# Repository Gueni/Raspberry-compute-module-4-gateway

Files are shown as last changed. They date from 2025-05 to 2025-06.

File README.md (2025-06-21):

# Compute Module 4 Gateway

Compact industrial-grade gatewaysolution based on Raspberry Pi Compute Module 4 (CM4) with extensive connectivity options including USB, Ethernet, cellular, and more.

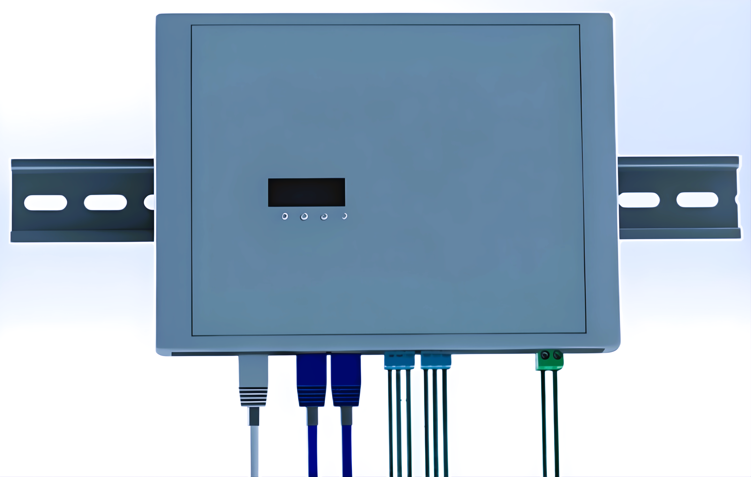
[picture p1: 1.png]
Gateway Overview

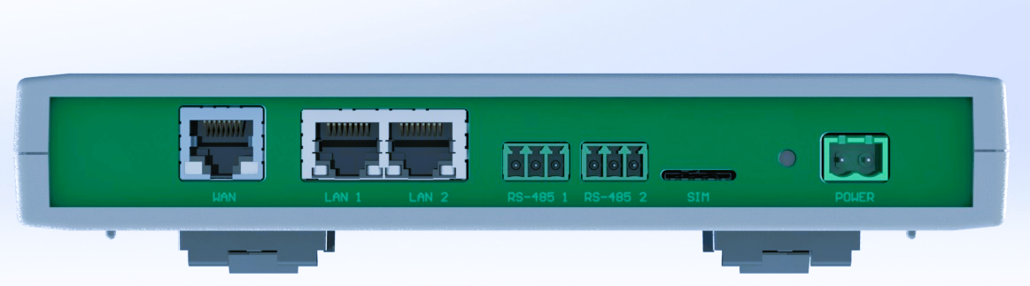
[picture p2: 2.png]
Gateway bottom

## Features

- **Raspberry Pi CM4** at its core
- **Dual Power Supply** with LMR33640 switching regulators
- **USB Hub** with USB2514B controller (4 downstream ports)
- **Cellular Connectivity** via LARA-R6 4G/LTE module
- **Dual Ethernet** with LAN9500A controllers
- **SD Card Interface** with MAX4996 selection.
- **Real-Time Clock** (MCP7940NT)
- **Supervisory Circuitry** with PIC16F18857
- **OLED Display** interface (128x32)
- **Multiple GPIO** breakout options

## Hardware Specifications
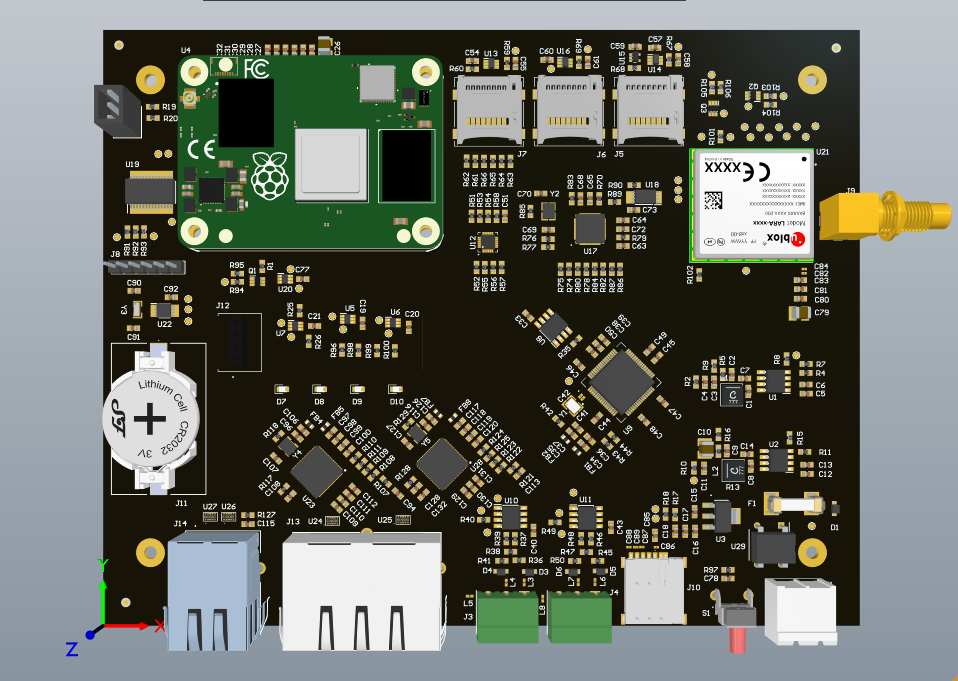
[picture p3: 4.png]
PCB3D

### Power Supply
- Input voltage: 5V DC
- Dual LMR33640 switching regulators (3.8V and 5V outputs)
- TLV1117LV33 LDO for 3.3V supply
- Power monitoring and control

### Connectivity
- 4x USB 2.0 ports (via USB2514B hub)
- 2x Ethernet ports (10/100 via LAN9500A)
- Cellular modem (u-blox LARA-R6 4G/LTE)
- SD card slot with write protection

### Interfaces 
- I2C for RTC and OLED display
- Multiple GPIO breakout
- Status LEDs (power, network, error, warning)
- Reset and user buttons

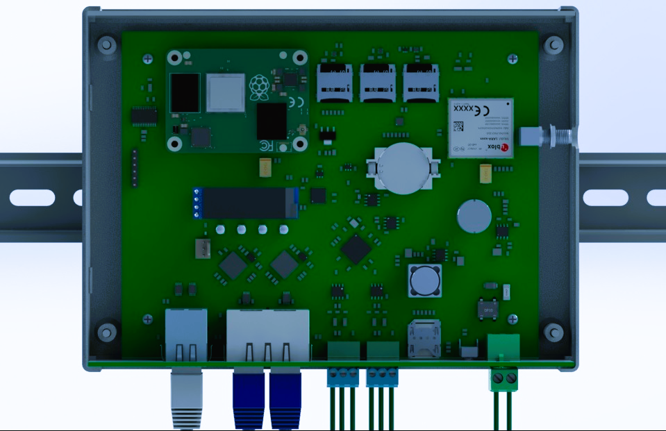
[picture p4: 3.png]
Gateway open

## Schematic Overview

The design consists of several key sections:

1. **Power Supply** 
   - Dual LMR33640 switching regulators
   - 3.3V LDO regulator
   - Power monitoring circuitry

2. **Compute Module 4 Interface** 
   - CM4 pin connections
   - GPIO breakout
   - Status LEDs

3. **SD Card Interface** 
   - MAX4996 protection IC
   - Dual SD card slots

4. **USB Hub** 
   - USB2514B controller
   - ESD protection
   - Port power management

5. **CPU Supervisor** 
   - PIC16F18857 microcontroller
   - System monitoring
   - Reset control

6. **Cellular Modem** 
   - u-blox LARA-R6 module
   - SIM card interface
   - USB connection

7. **Ethernet Interfaces** 
   - Dual LAN9500A controllers
   - Magnetics and protection
   - LED indicators

8. **I2C Peripherals** 
   - MCP7940NT RTC with battery backup
   - OLED display interface

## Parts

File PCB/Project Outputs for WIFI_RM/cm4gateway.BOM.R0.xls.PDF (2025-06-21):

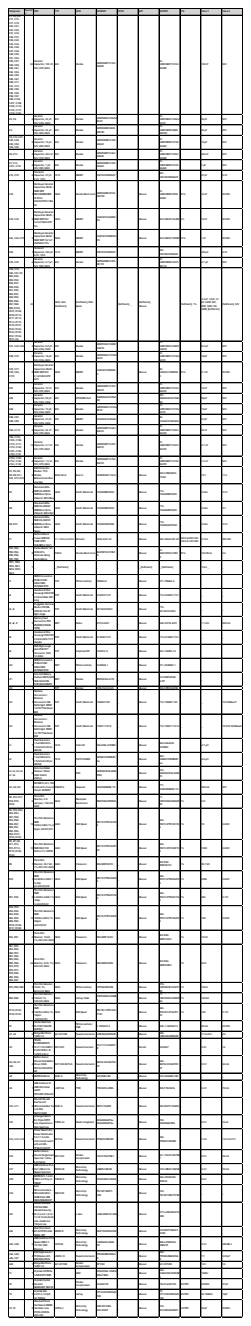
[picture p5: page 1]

C1, C4, C8, C11, C15, C17, C19, C20, C21, C23, C25, C31, C33, C36, C37, C38, C40, C43, C44, C45, C46, C47, C48, C49, C50, C51, C54, C55, C57, C58, C59, C60, C61, C62, C63, C64, C65, C66, C67, C68, C71, C72, C73, C80, C85, C92, C95, C96, C97, C98, C102, C107, C108, C109, C114, C116, C117, C118, C122, | Ceramic 62 Capacitor, 100 nF, 50V, X7R, 0603 | 603 | Murata | GRM188R71H104 KA93D | | | 81-GRM188R71H104 KA93D | | 100 nF | 50V

C2, C9 | Ceramic 2 Capacitor, 22 pF, 50V, C0G, 0603 | 603 | Murata | GRM1885C1H220J A01D | | | 81-GRM1885C1H220J A01D | | 22 pF | 50V

C3 | 1 Ceramic Capacitor, 22 µF, 25V, X5R, 0603 | 603 | Murata | GRM188R61E226 ME15D | | | 81-GRM188R61E226 ME15D | | 22 µF | 25V

C5, C12, C27, C28, C29, C30, C52, C53, C56 | Ceramic 9 Capacitor, 10 µF, 50V, X5R, 0603 | 603 | Murata | GRM188R61H106 KAALD | | | 81-GRM188R61H106 KAALD | | 10 µF | 50V

C6, C13 | Ceramic 2 Capacitor, 220 nF, 50V, X7R, 0603 | 603 | Murata | GRM188R71H224 KA93D | | | 81-GRM188R71H224 KA93D | | 220 nF | 50V

C7, C14, C101, C121 | 4 Ceramic Capacitor, 1 µF, 50V, X5R, 0603 | 603 | Murata | GRM188R61H105 KAALD | | | 81-GRM188R61H105 KAALD | | 1 µF | 50V

C10, C79 | 2 Tantalum Capacitor, 47 µF, 6.3V, 1210 | 1210 | KEMET | T491D476K006AT | | | 581-T491D476K006AT | | 47 µF | 6.3V

C16 | Multilayer Ceramic Capacitors MLCC-1 SMD/SMT RECOMMENDED ALT810-C3225X7R1H1062 50 | 0603 | MurataElectronics | GRM188R61E106 MA73D | _ | Mouser | 81-GRM188R61E106 MA3D | 20% | 10uF | 50VDC

C18, C32 | Multilayer Ceramic Capacitors MLCC-2 SMD/SMT50V 0.01uF0603X7R 5% | 0603 | KEMET | C0603C103J5RAC TU | _ | Mouser | 80-C0603C103J5R | 5% | 10nF | 50VDC

C22, C24, C75 | 3 Multilayer Ceramic Capacitors MLCC-SMD/SMT10v1uF X5R060310% | 0603 | KEMET | C0603C105K8PAC TU | _ | Mouser | 80-C0603C105K8P 10% | | 1uF | 50VDC

C26 | 1 Tantalum Capacitor, 330 µF, 6.3V, 1210 | 1210 | KEMET | T491D337K006AT | | | 581-T491D337K006AT | | 330 µF | 6.3V

C34, C35 | Ceramic 2 Capacitor, 4.7 µF, 50V, X5R, 0603 | 603 | Murata | GRM188R61H475 KE11D | | | 81-GRM188R61H475 KE11D | | 4.7 µF | 50V

C39, C74, C90, C91, R1, R25, R26, R29, R30, R36, R37, R38, R39, R41, R45, R46, R47, R48, R50, R85, R96, R97, R98, R99, R100, R107, R108, R109, R110, R111, R113, R114, R115, R116, R121, R122, R123, R124, R125, R127, R130, R131, U4 | 43 | 0603, 603, [NoParam] | [NoParam], KOA Speer | | [NoParam], _ | [NoParam], Mouser | | [NoParam], 1% | 3.3uF, 10pF, 12 pF, 330R, 4K7, 56R, 120R, 1M, 49R9, [NoParam] | [NoParam], 50V

C41, C42, C84 | 3 Ceramic Capacitor, 8.2 pF, 50V, C0G, 0402 | 402 | Murata | GRM1555C1H8R2 CA01D | | | 81-GRM1555C1H8R2 CA01D | | 8.2 pF | 50V

C69, C70 | Ceramic 2 Capacitor, 18 pF, 50V, C0G, 0603 | 603 | Murata | GRM1885C1H180J A01D | | | 81-GRM1885C1H180J A01D | | 18 pF | 50V

C76, C77, C78, C93, C115 | Multilayer Ceramic 5 Capacitors MLCC-SMD/SMT50V 0.1uF0603X7R 20% | 0603 | KEMET | C0603C104M5RA C | _ | Mouser | 80-C0603C104M5RA C | 20% | 0.1uF | 50VDC

C81 | 1 Ceramic Capacitor, 10 nF, 50V, X7R, 0603 | 603 | Murata | GRM188R71H103 KA01D | | | 81-GRM188R71H103 KA01D | | 10 nF | 50V

C82 | Ceramic 1 Capacitor, 56 pF, 50V, C0G, 0402 | 402 | KYOCERAAVX | KGM05ACG1H560 KH | | | 581-KGM05ACG1H560 KH | | 56 pF | 50V

C83 | 1 Ceramic Capacitor, 15 pF, 50V, C0G, 0603 | 603 | Murata | GRM1885C1H150J A01D | | | 81-GRM1885C1H150J A01D | | 15 pF | 50V

C86, C87, C88, C89 | Ceramic 4 Capacitor, 47 pF, 50V, C0G, 0402 | 402 | KEMET | C0402C470J5GAC | | | 80-C0402C470J5GAC | | 47 pF | 50V

C94, C113 | 2 Ceramic Capacitor, 22 nF, 50V, X7R, 0603 | 603 | Murata | GRM188R71H223 KA01D | | | 81-GRM188R71H223 KA01D | | 22 nF | 50V

C99, C103, C105, C106, C110, C111, C119, C123, C125, C126, C130, C131 | 12 Ceramic Capacitor, 4.7 nF, 50V, X7R, 0603 | 603 | Murata | GRM188R71H472 KA01D | | | 81-GRM188R71H472 KA01D | | 4.7 nF | 50V

C100, C104, C112, C120, C124, C132 | Ceramic 6 Capacitor, 1.5 nF, 50V, X7R, 0603 | 603 | Murata | GRM188R71H152 KA01D | | | 81-GRM188R71H152 KA01D | | 1.5 nF | 50V

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

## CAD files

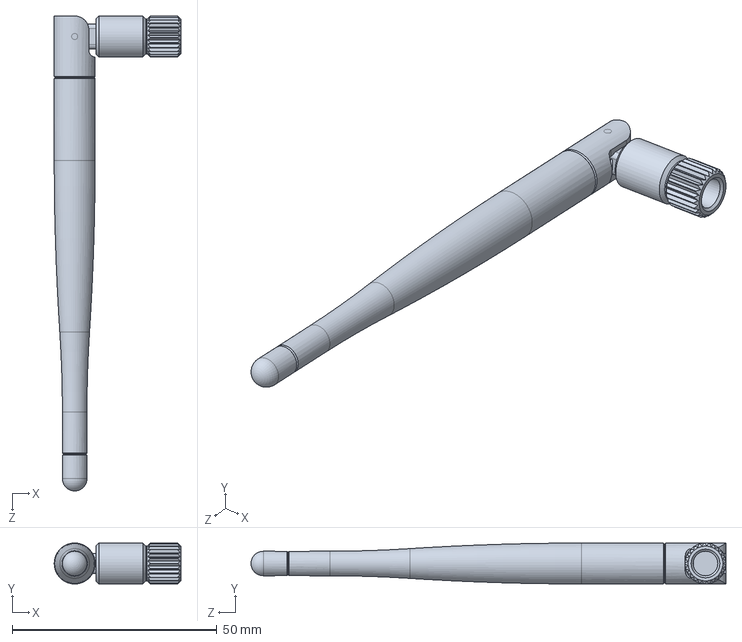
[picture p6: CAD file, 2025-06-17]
3D/SMA to UMCX Cable.SLDPRT
30.9 x 10.00 x 115.9 mm

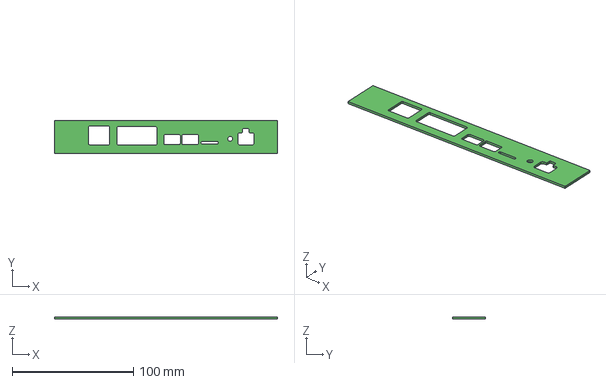
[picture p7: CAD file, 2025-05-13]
Buttom_cover/Project Outputs for Buttom_cover/Buttom_cover.step
183.7 x 27.0 x 1.59 mm

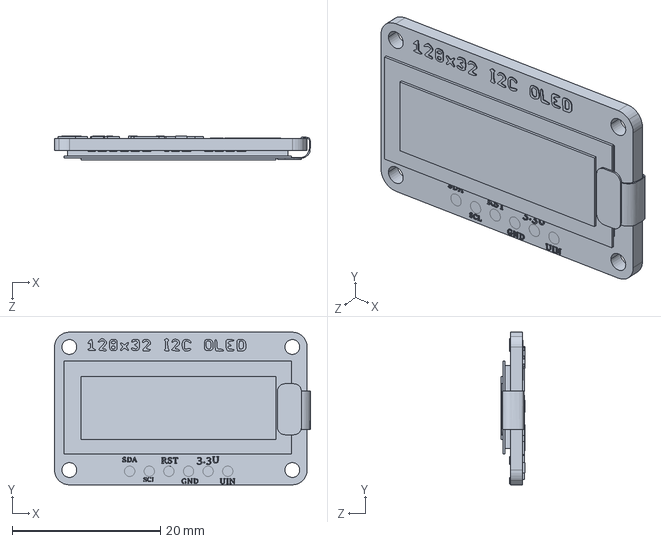
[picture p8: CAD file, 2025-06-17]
3D/128x32oled.SLDPRT
34.5 x 20.6 x 3.30 mm

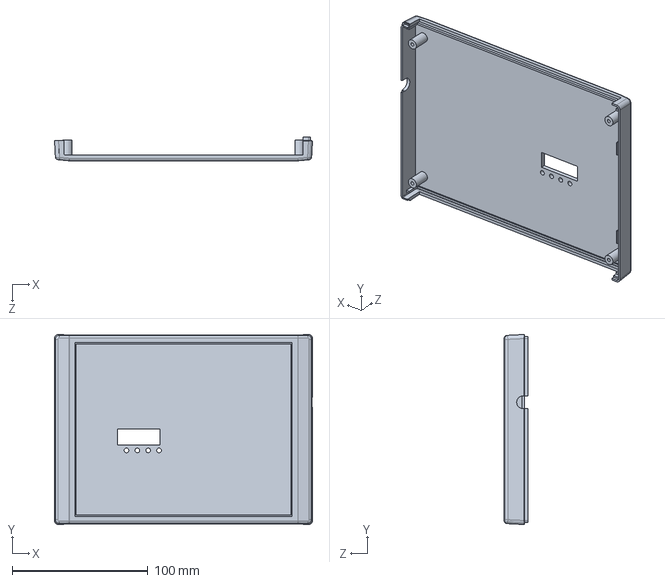
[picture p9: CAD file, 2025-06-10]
3D/2055S-T-unistik.SLDPRT
190.0 x 140.0 x 17.5 mm

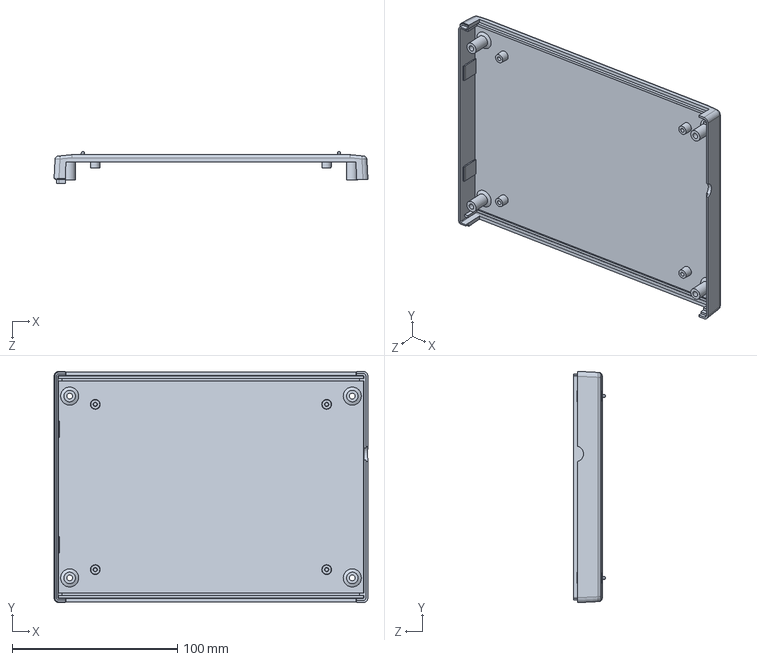
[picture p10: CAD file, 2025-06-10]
3D/2055S-B-unistik.SLDPRT
190.0 x 140.0 x 19.5 mm

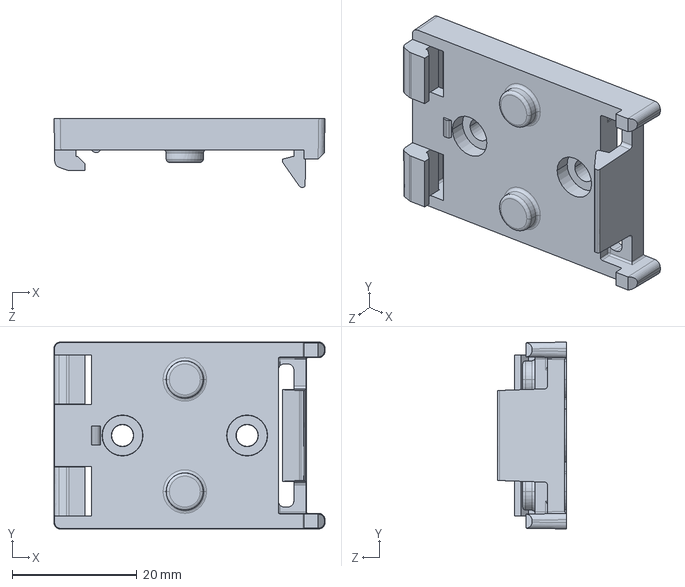
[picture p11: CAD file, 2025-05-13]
3D/TSH 35-2_1009012_3D_S.SLDPRT
43.5 x 30.0 x 11.0 mm

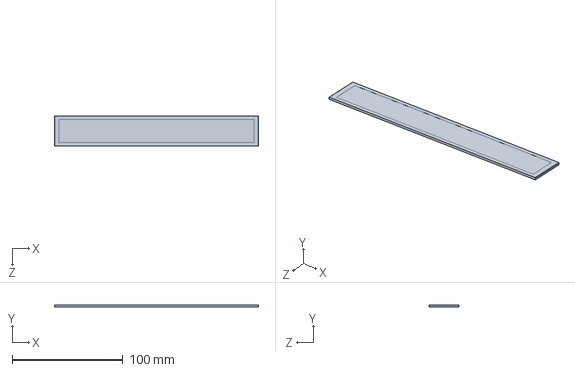
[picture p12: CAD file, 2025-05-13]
3D/2055S-PR1.SLDPRT
184.3 x 1.79 x 27.0 mm

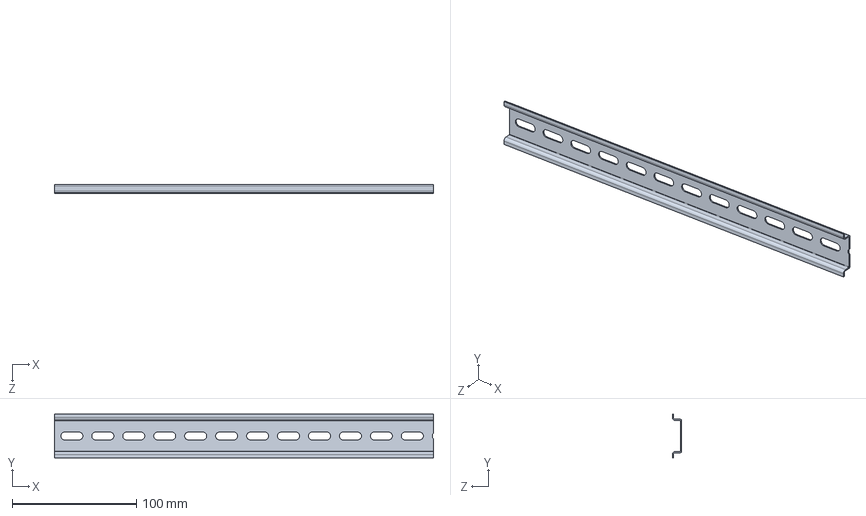
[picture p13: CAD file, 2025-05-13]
3D/TS 35 x 7.5.SLDPRT
304.8 x 35.0 x 7.50 mm

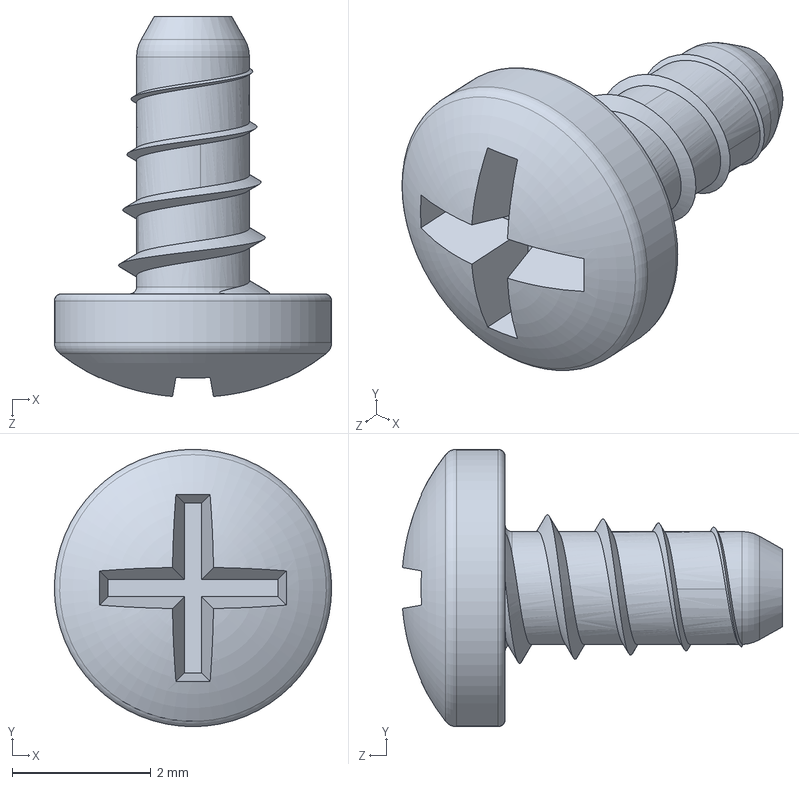
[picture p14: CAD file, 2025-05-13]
3D/Screw ST2.2.SLDPRT
4.00 x 4.00 x 5.48 mm

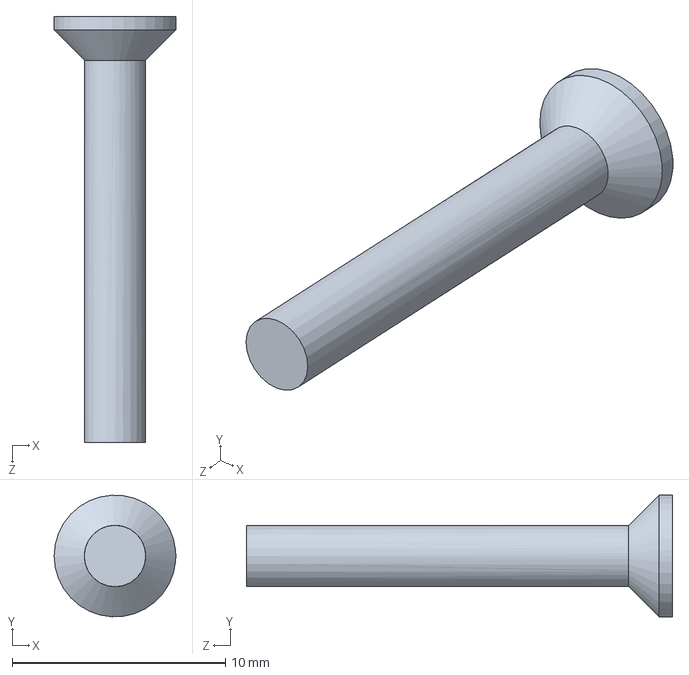
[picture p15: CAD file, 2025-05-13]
3D/Screw-M3-0.5x20mm-FH.SLDPRT
5.71 x 5.70 x 20.0 mm

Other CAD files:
3D/Buttom_cover1.SLDPRT

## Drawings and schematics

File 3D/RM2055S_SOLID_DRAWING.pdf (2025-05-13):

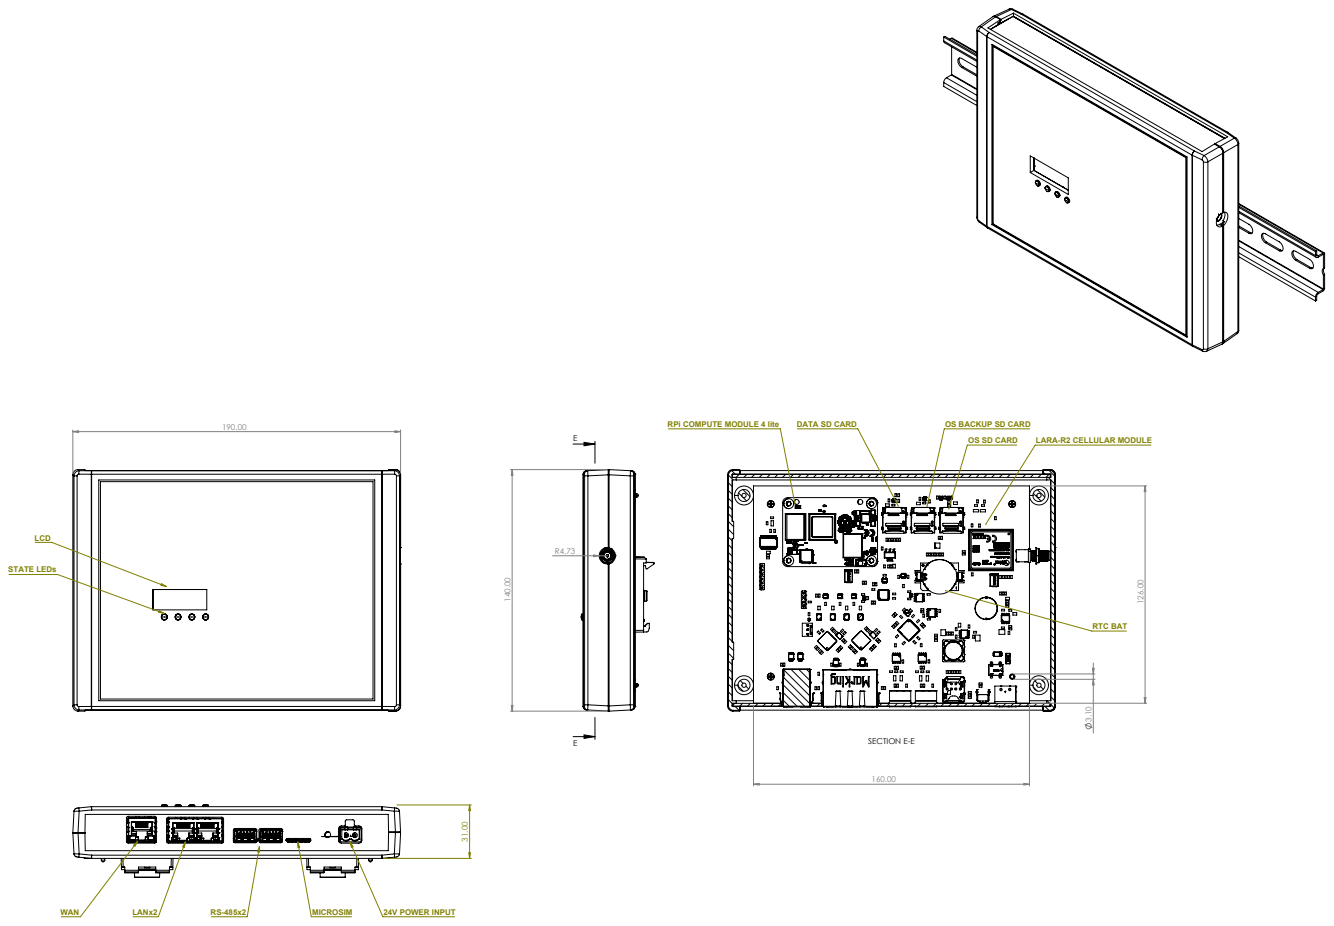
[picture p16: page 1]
STATE LEDs; WAN; LANx2; MICROSIM; 24V POWER INPUT; SECTION E-E; RTC BAT; DATA SD CARD; OS BACKUP SD CARD

RPi COMPUTE MODULE 4 lite

OS SD CARD

LARA-R2 CELLULAR MODULE

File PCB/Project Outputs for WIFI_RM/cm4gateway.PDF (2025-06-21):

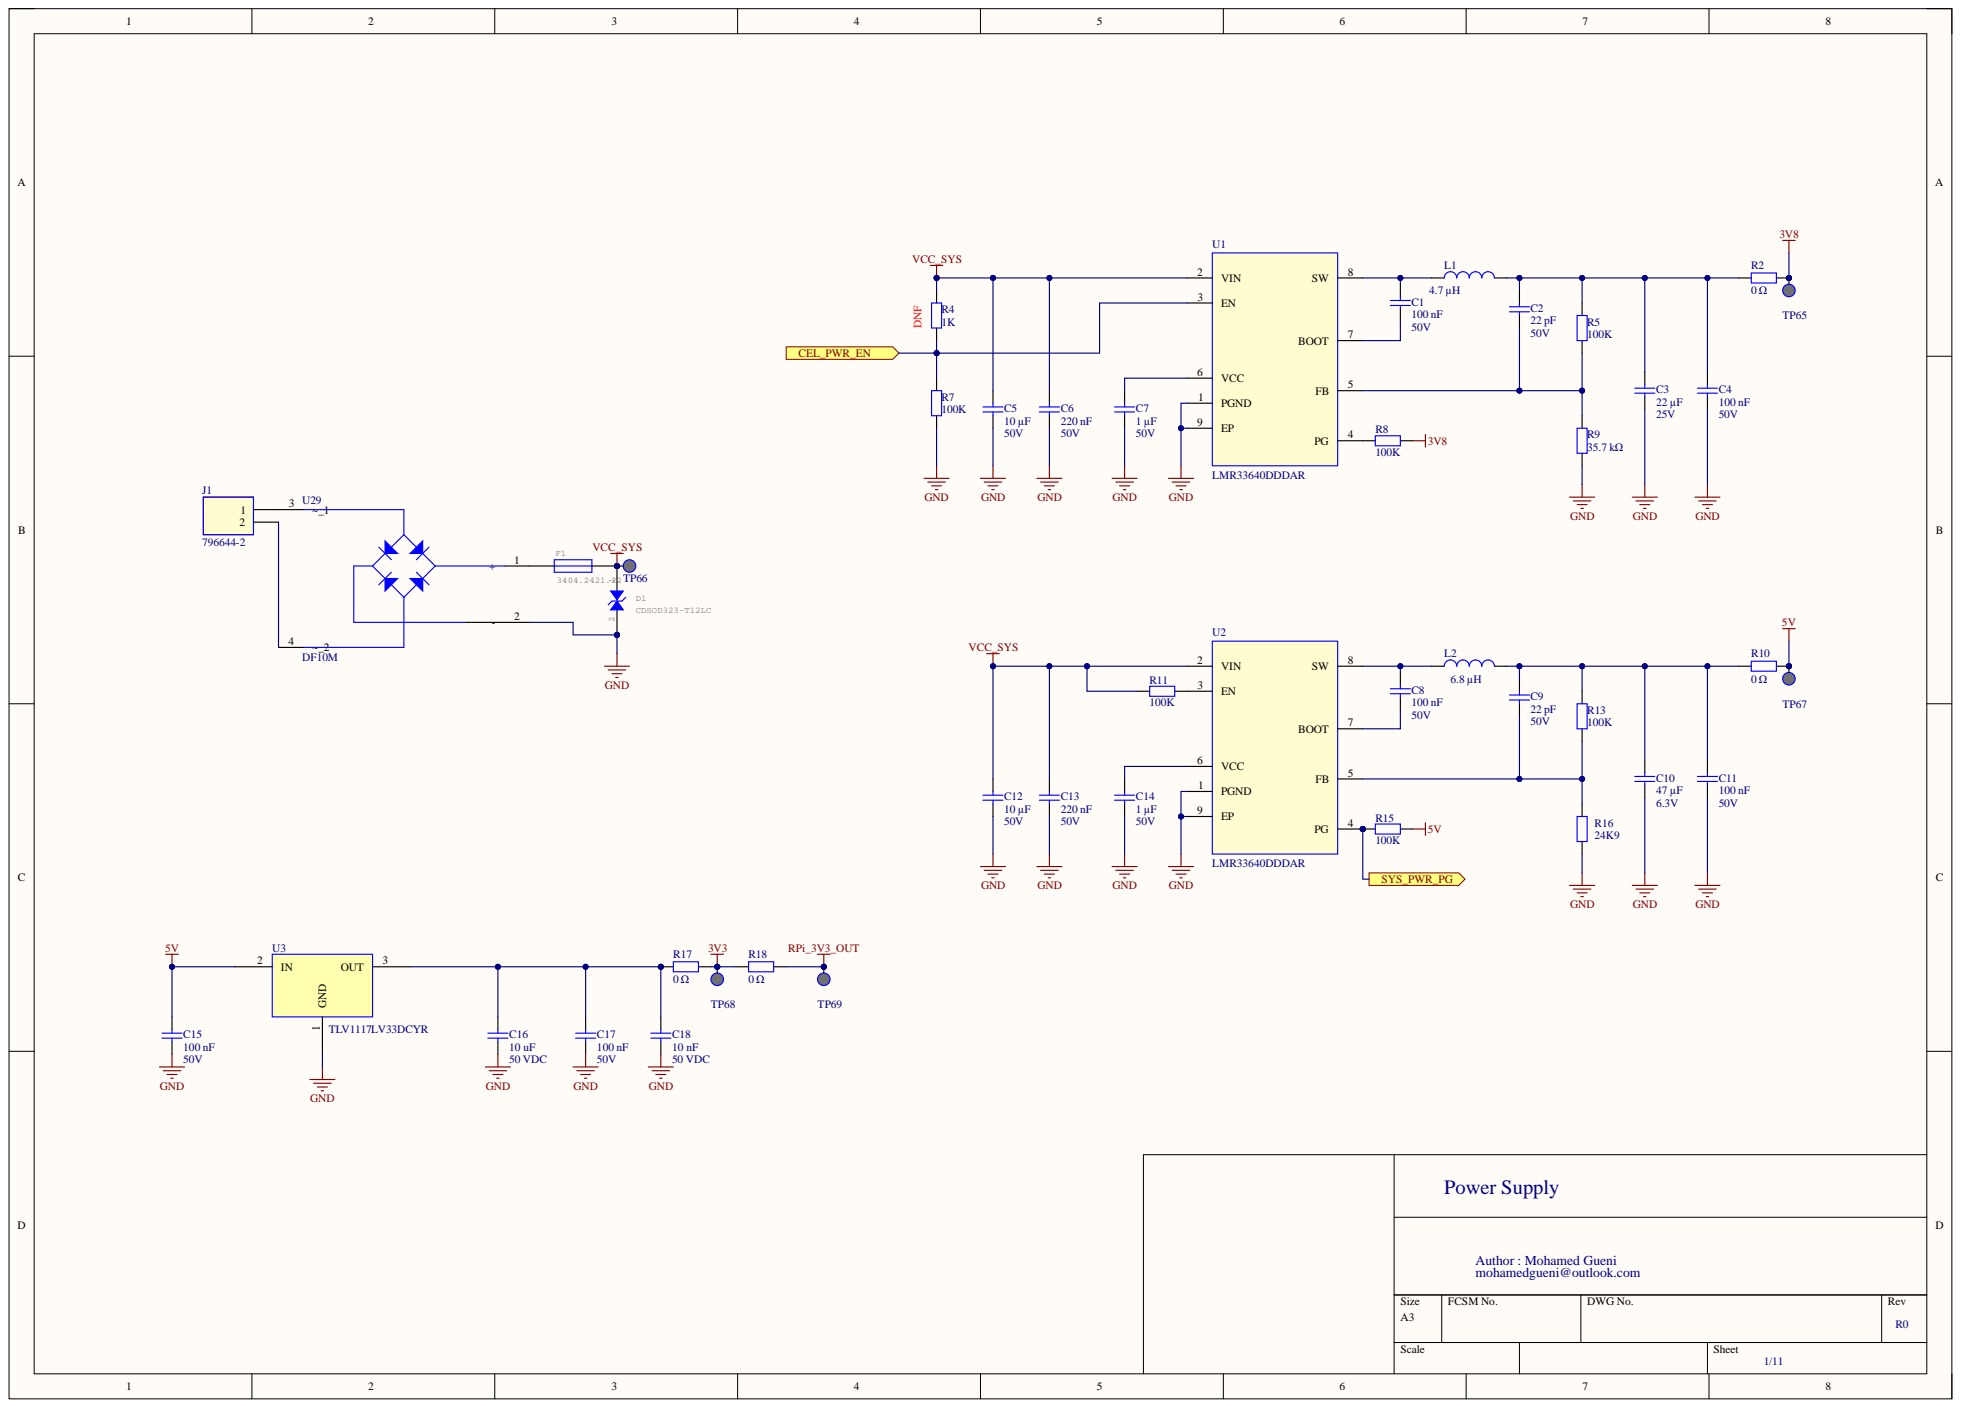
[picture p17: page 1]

Author : Mohamed Gueni mohamedgueni@outlook.com

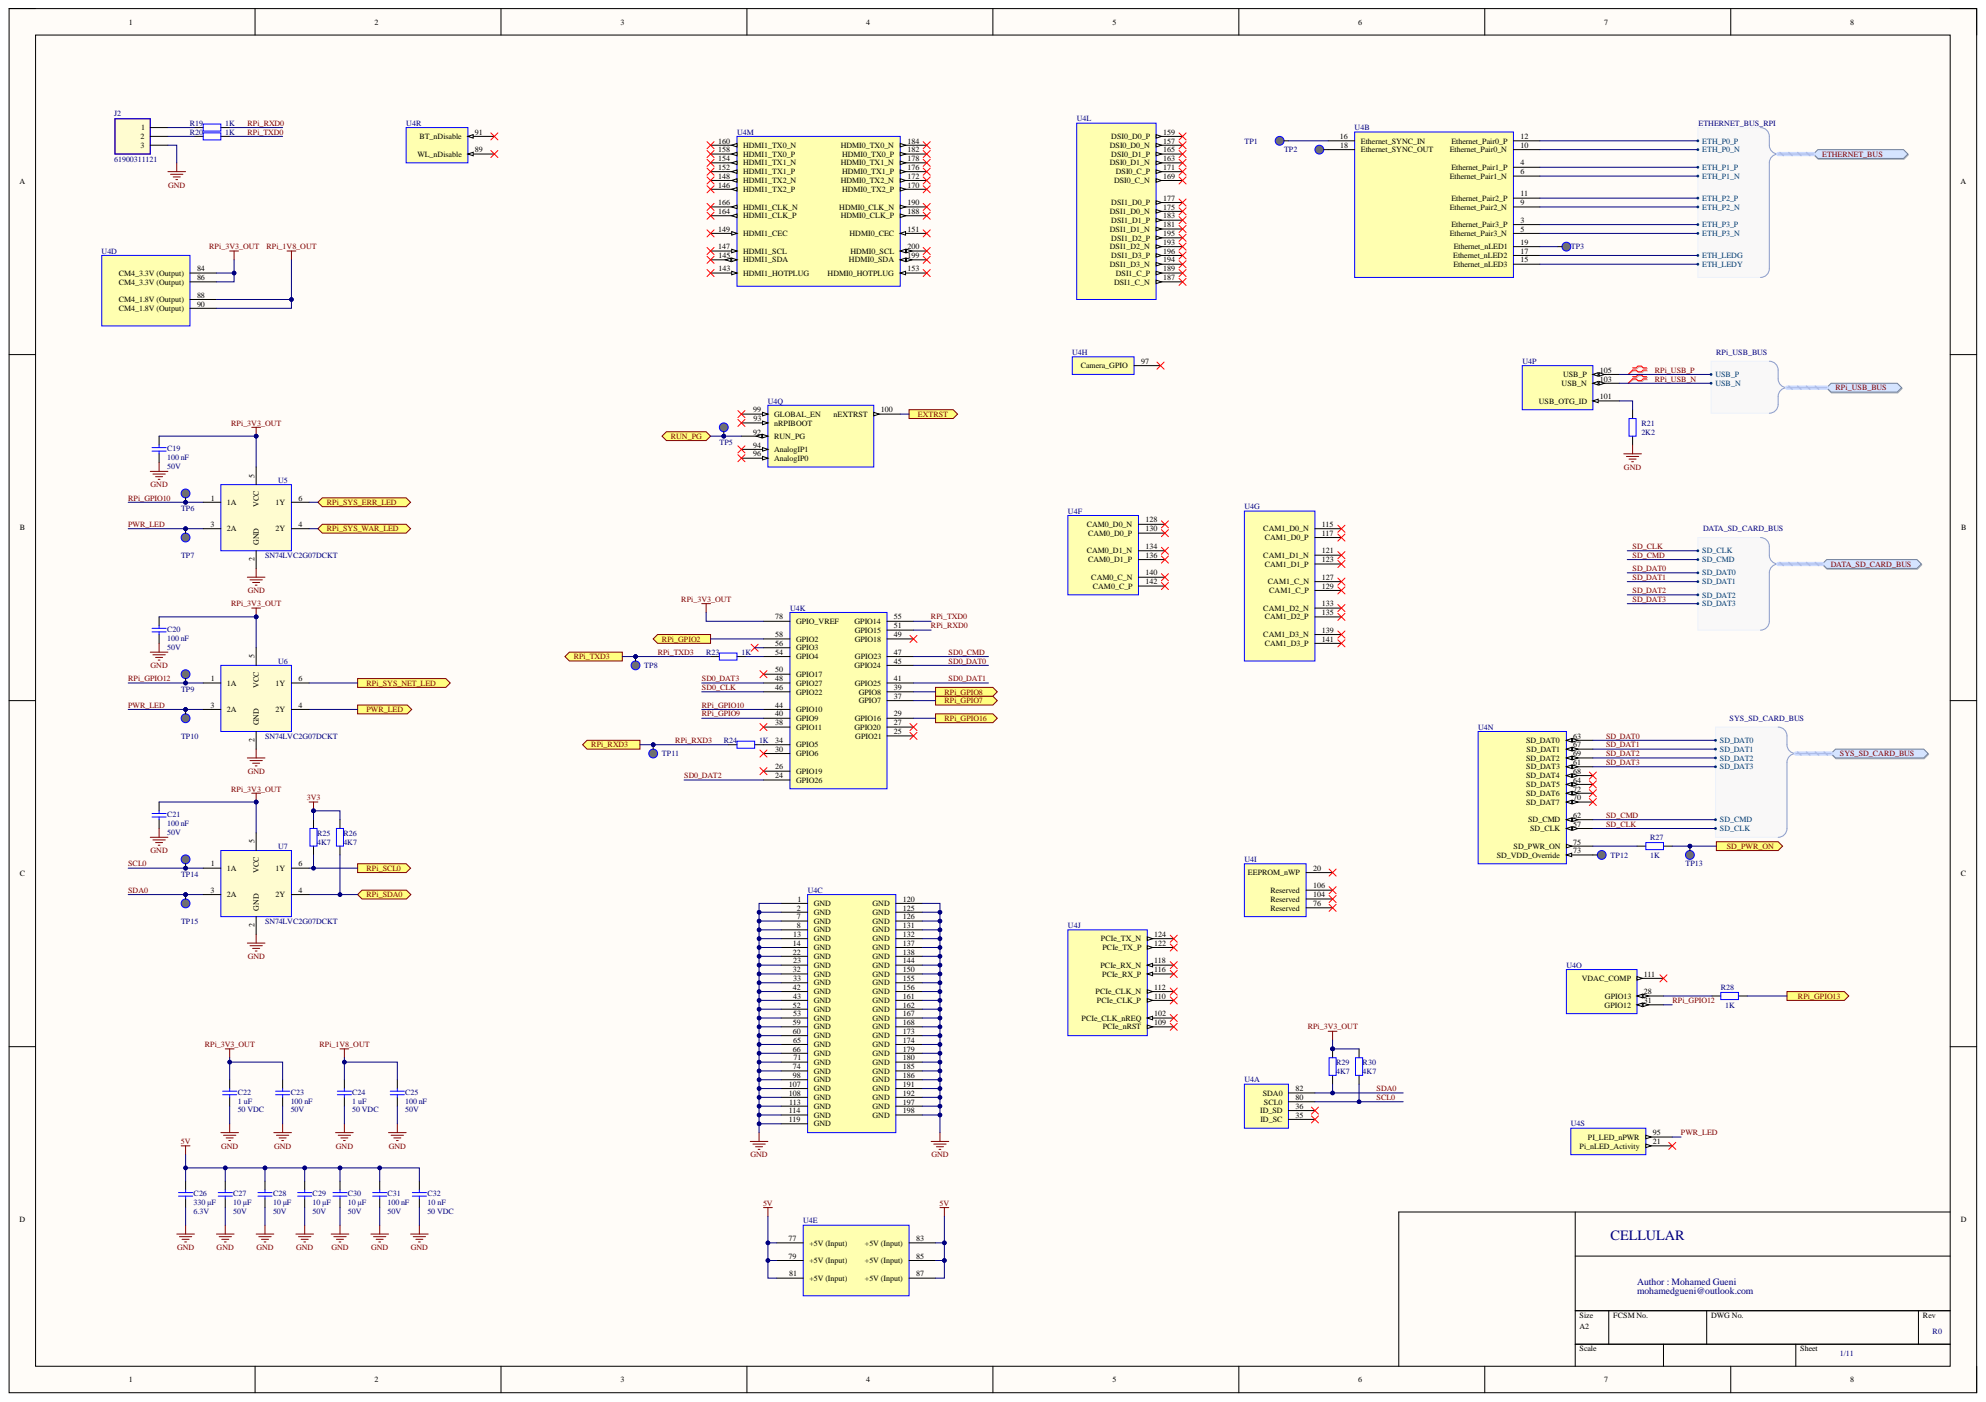
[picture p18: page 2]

Author : Mohamed Gueni mohamedgueni@outlook.com

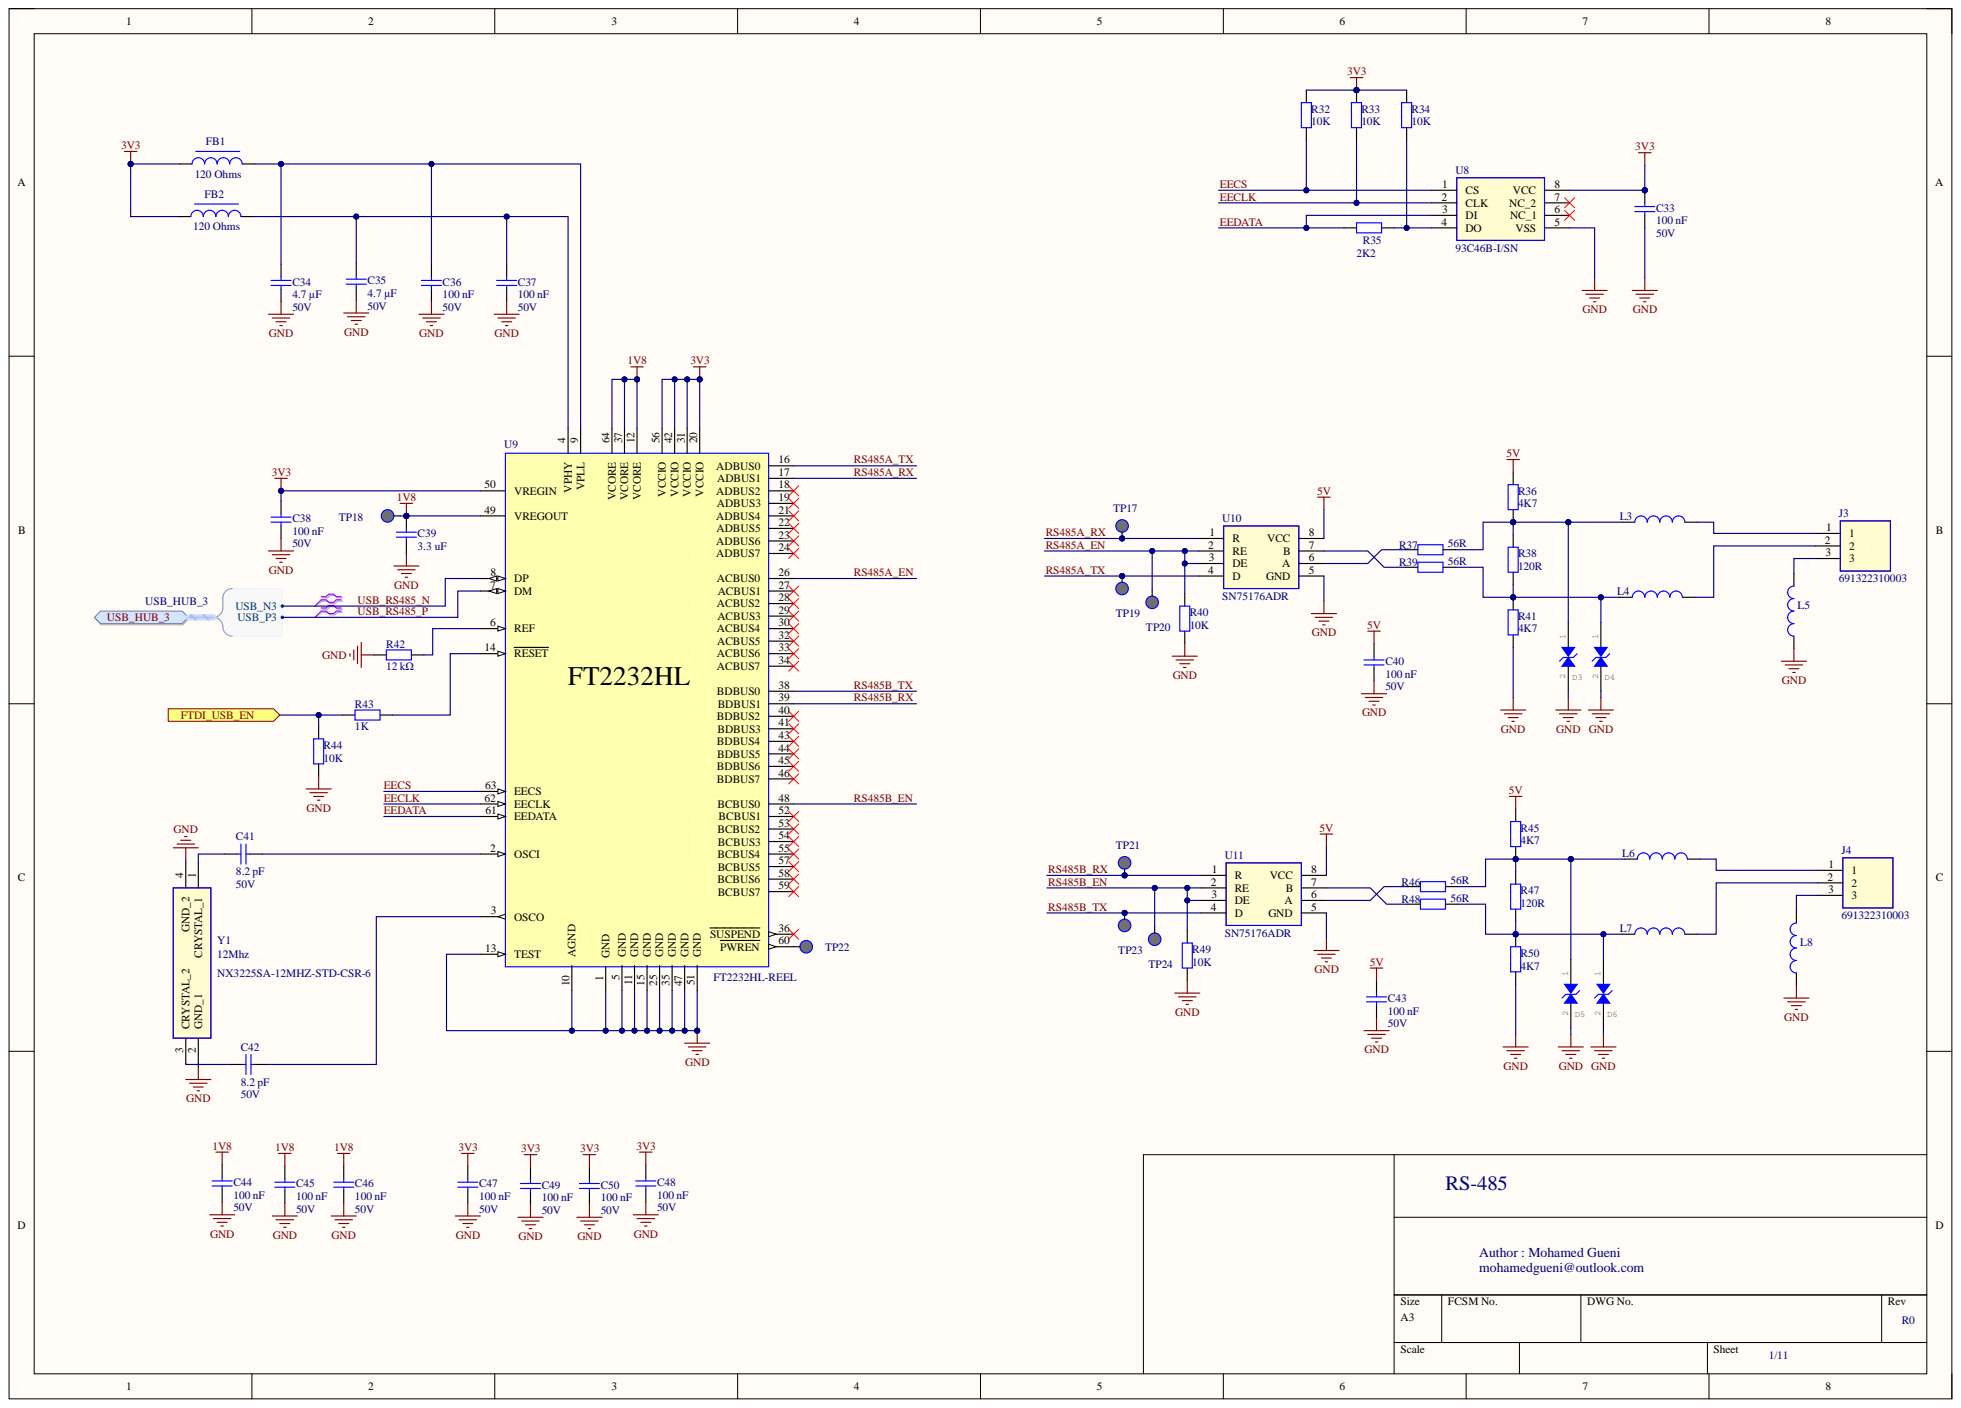
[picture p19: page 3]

VCCIO 20 VCCIO 31 VCCIO 42 VCCIO 56

USB_RS485 _N

GND | 7

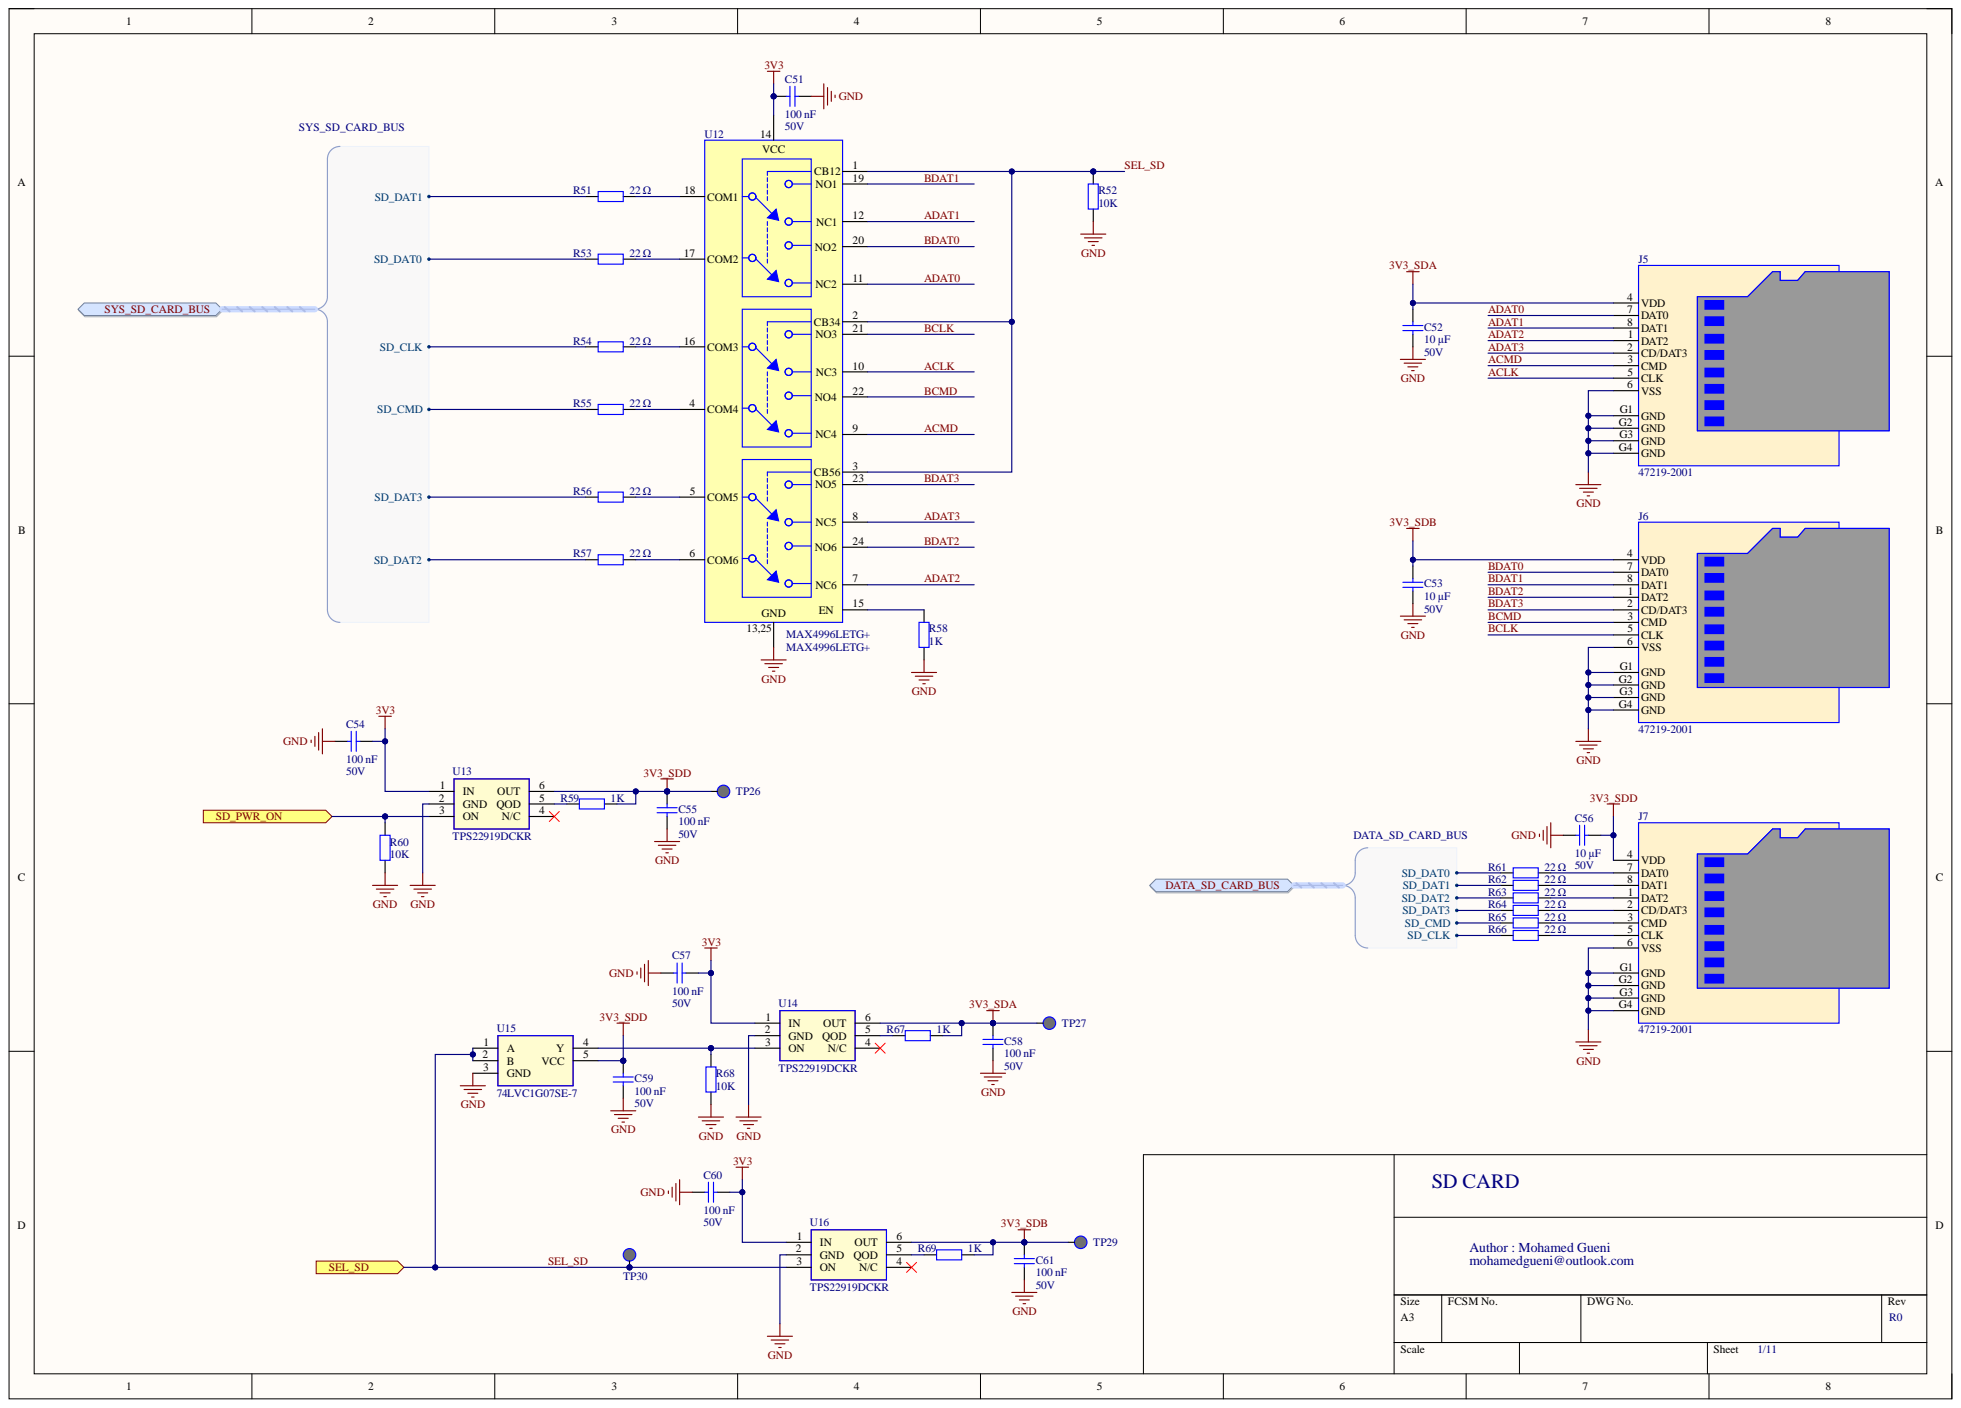
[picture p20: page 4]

Author : Mohamed Gueni mohamedgueni@outlook.com

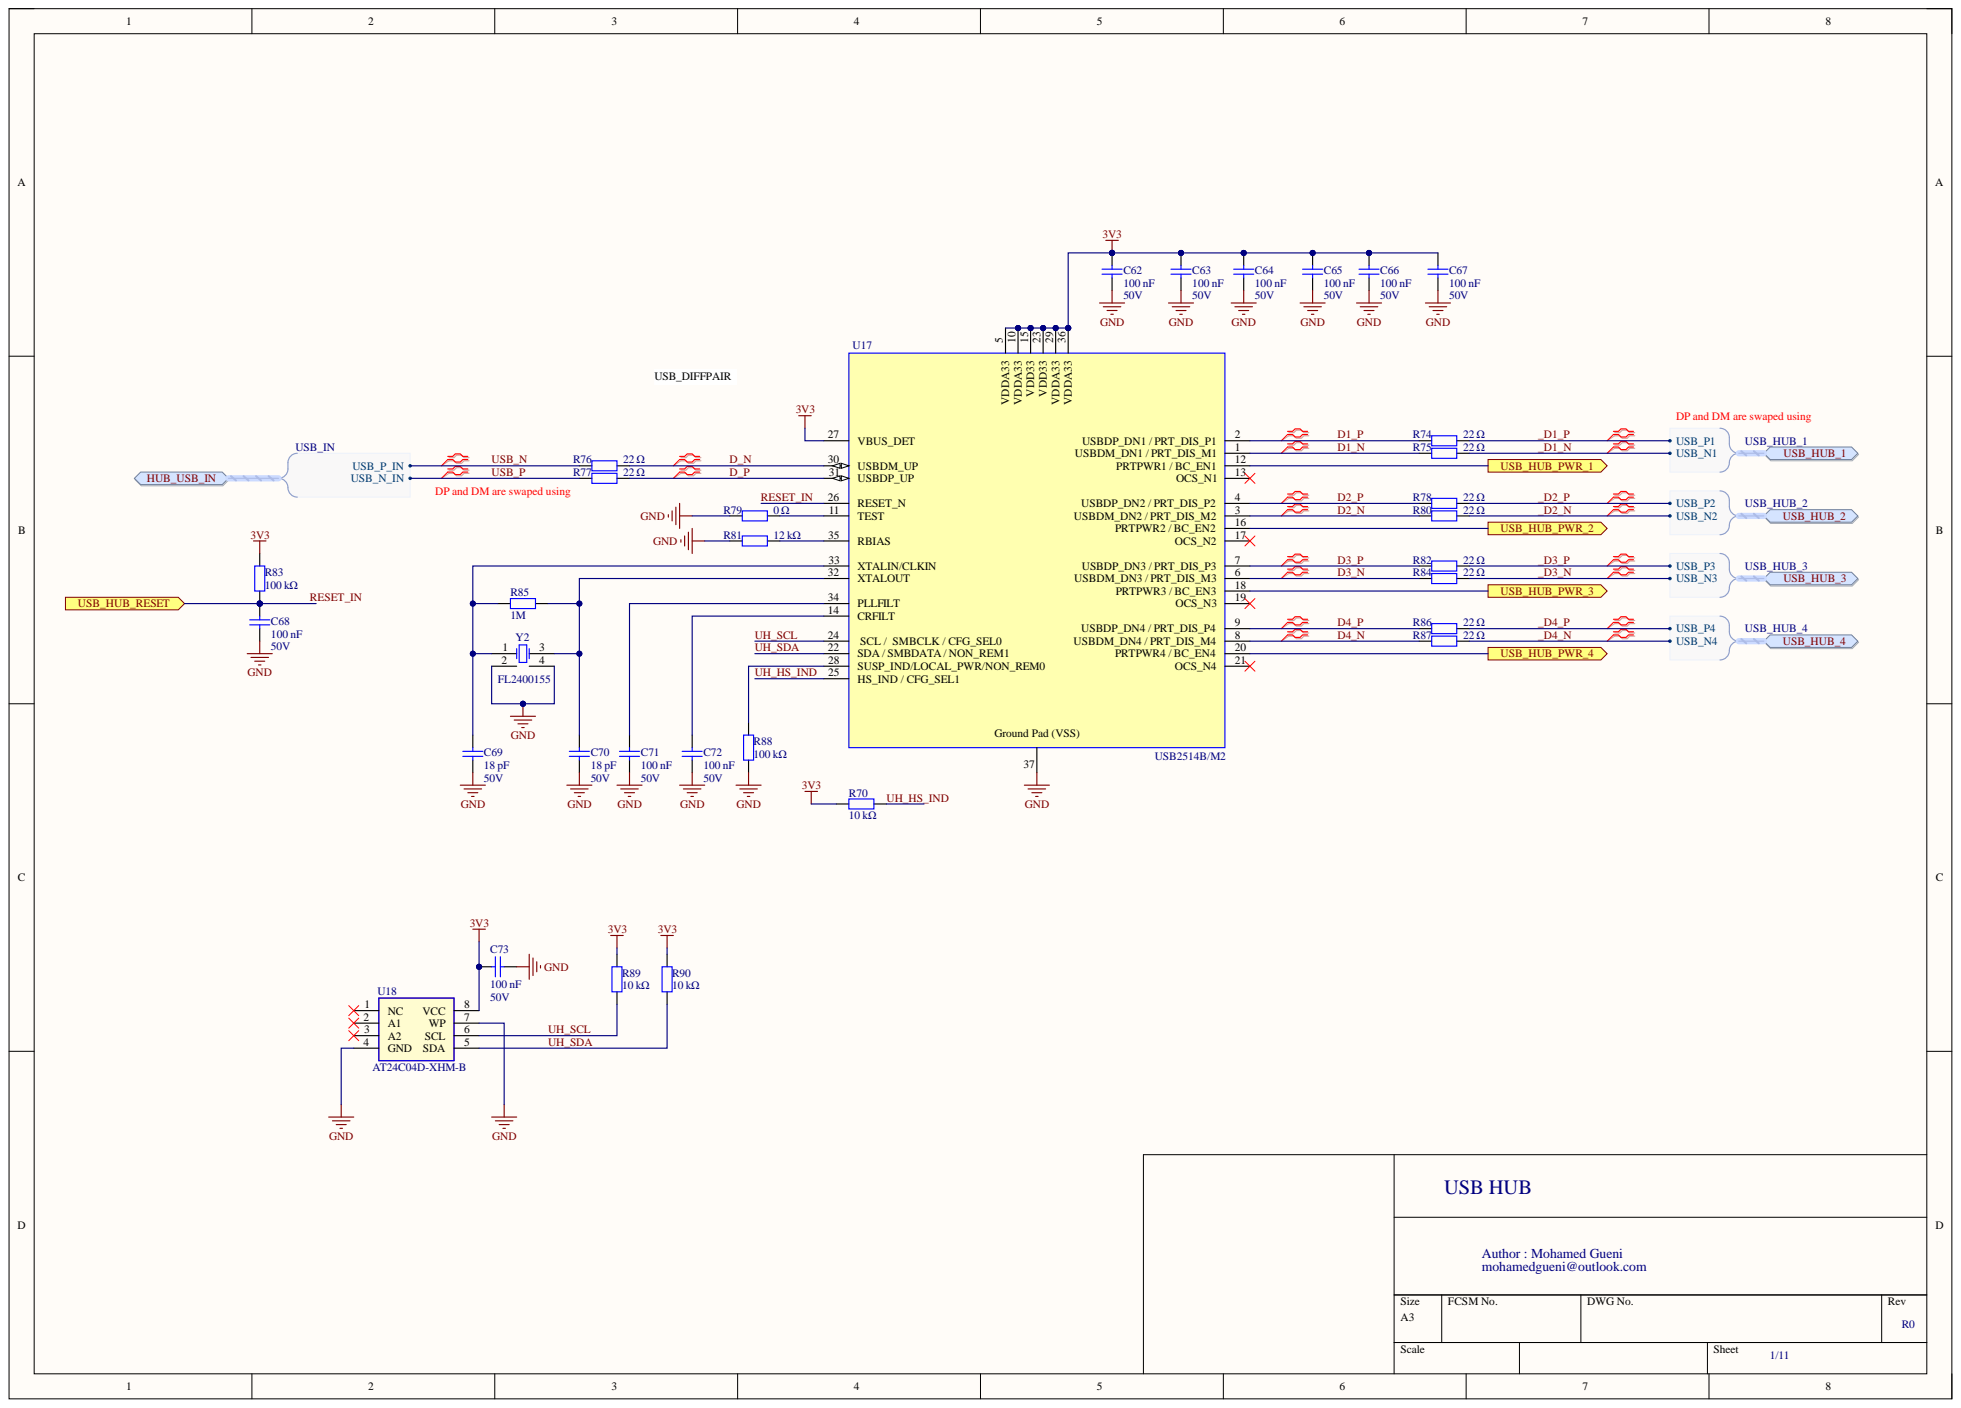
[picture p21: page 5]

DP and DM are swaped using

PLLFILT 34

1M | | CRFILT 14

UH_SCL | | SCL / SMBCLK / CFG_SEL0 24

Author : Mohamed Gueni mohamedgueni@outlook.com

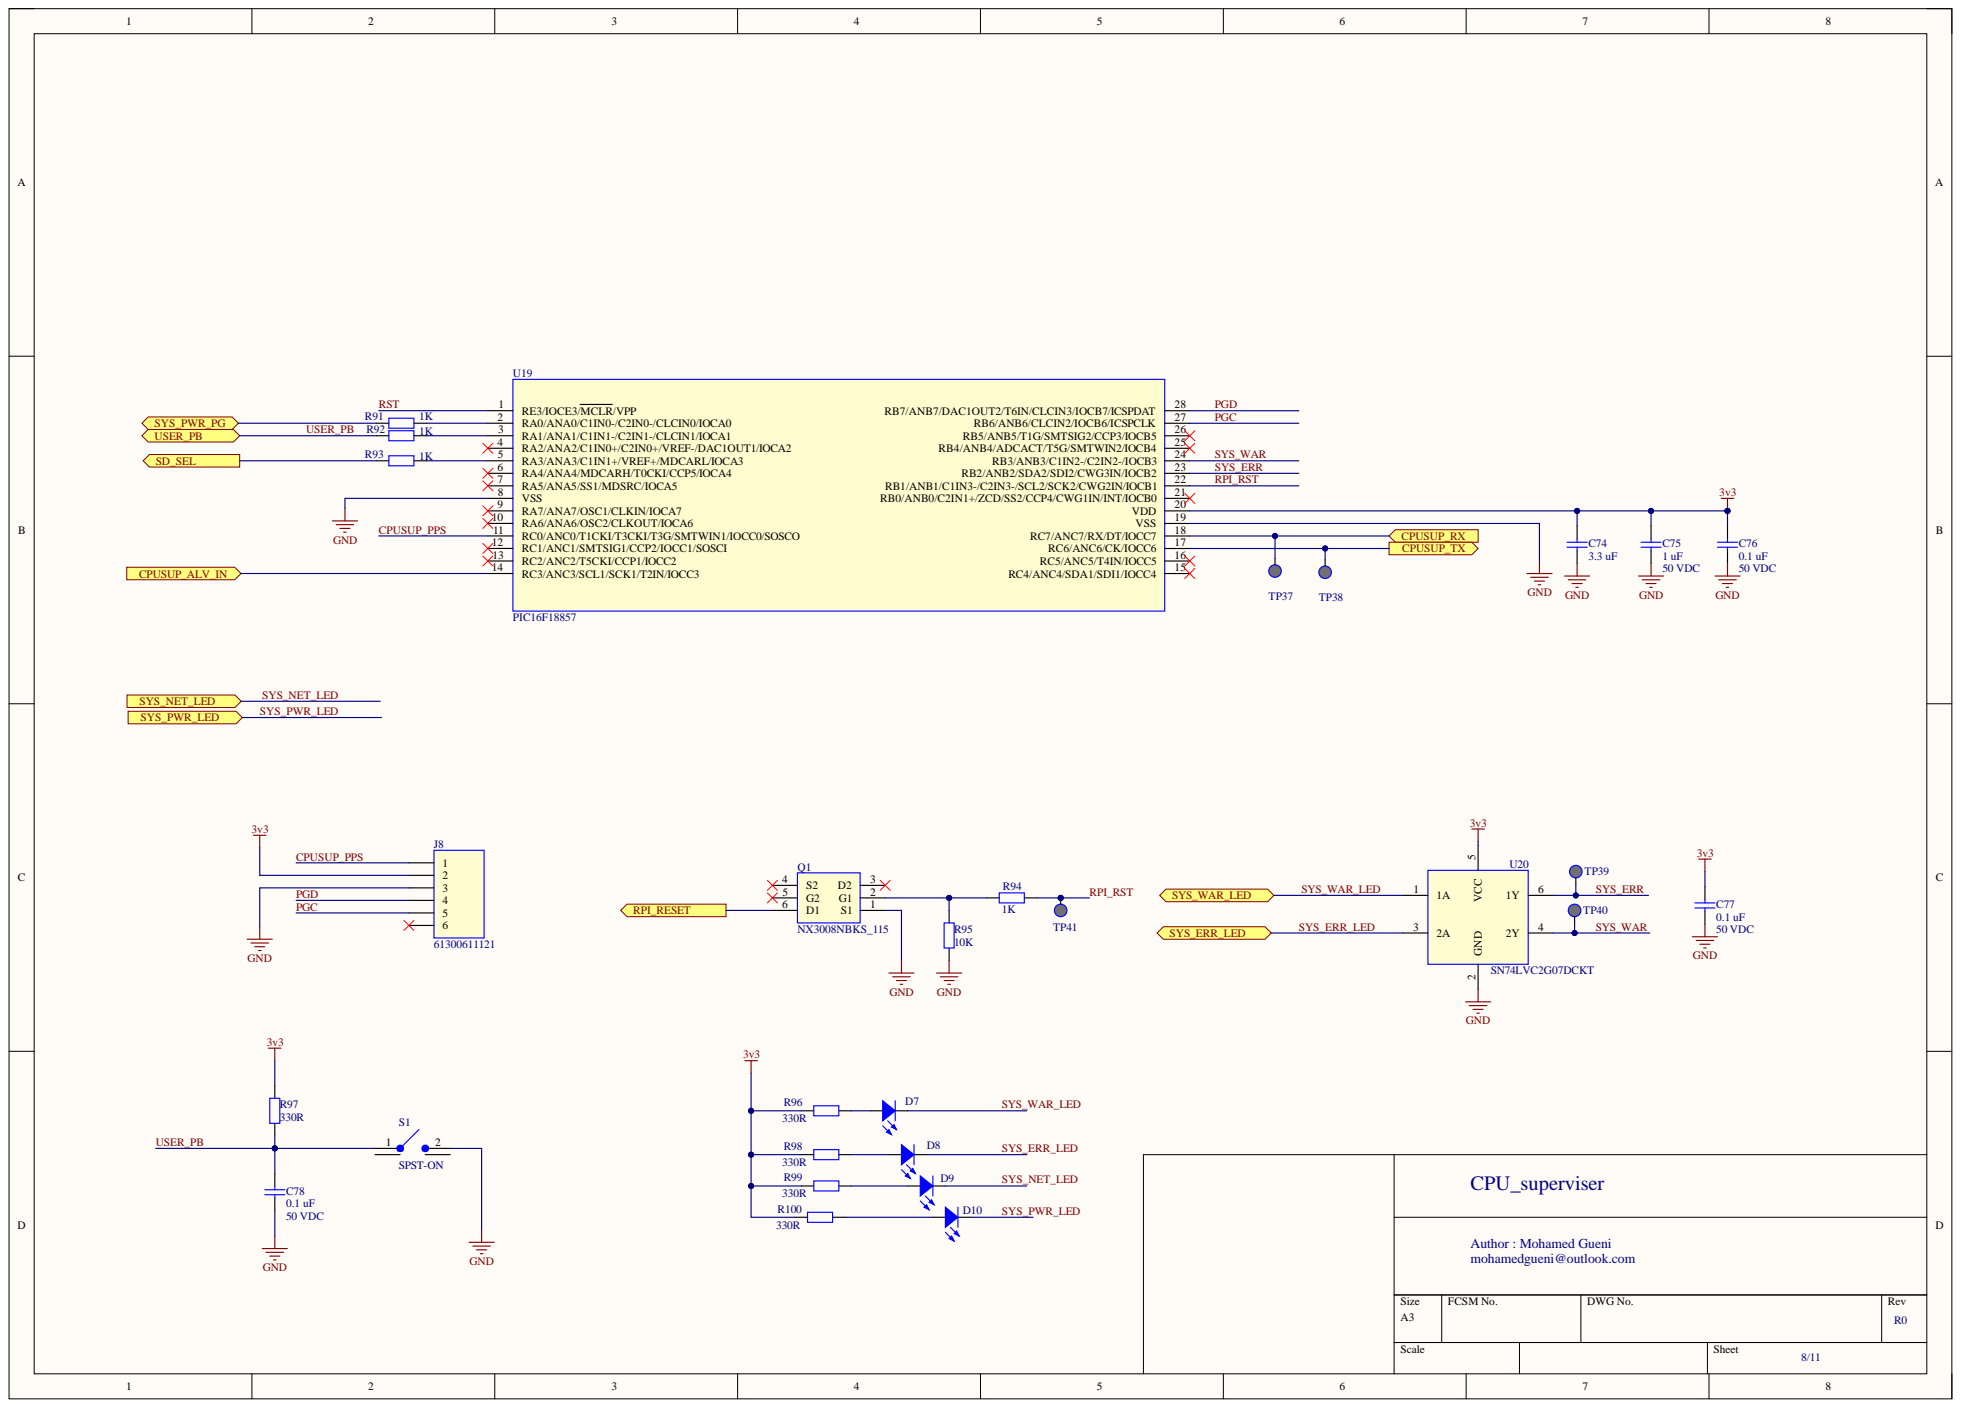
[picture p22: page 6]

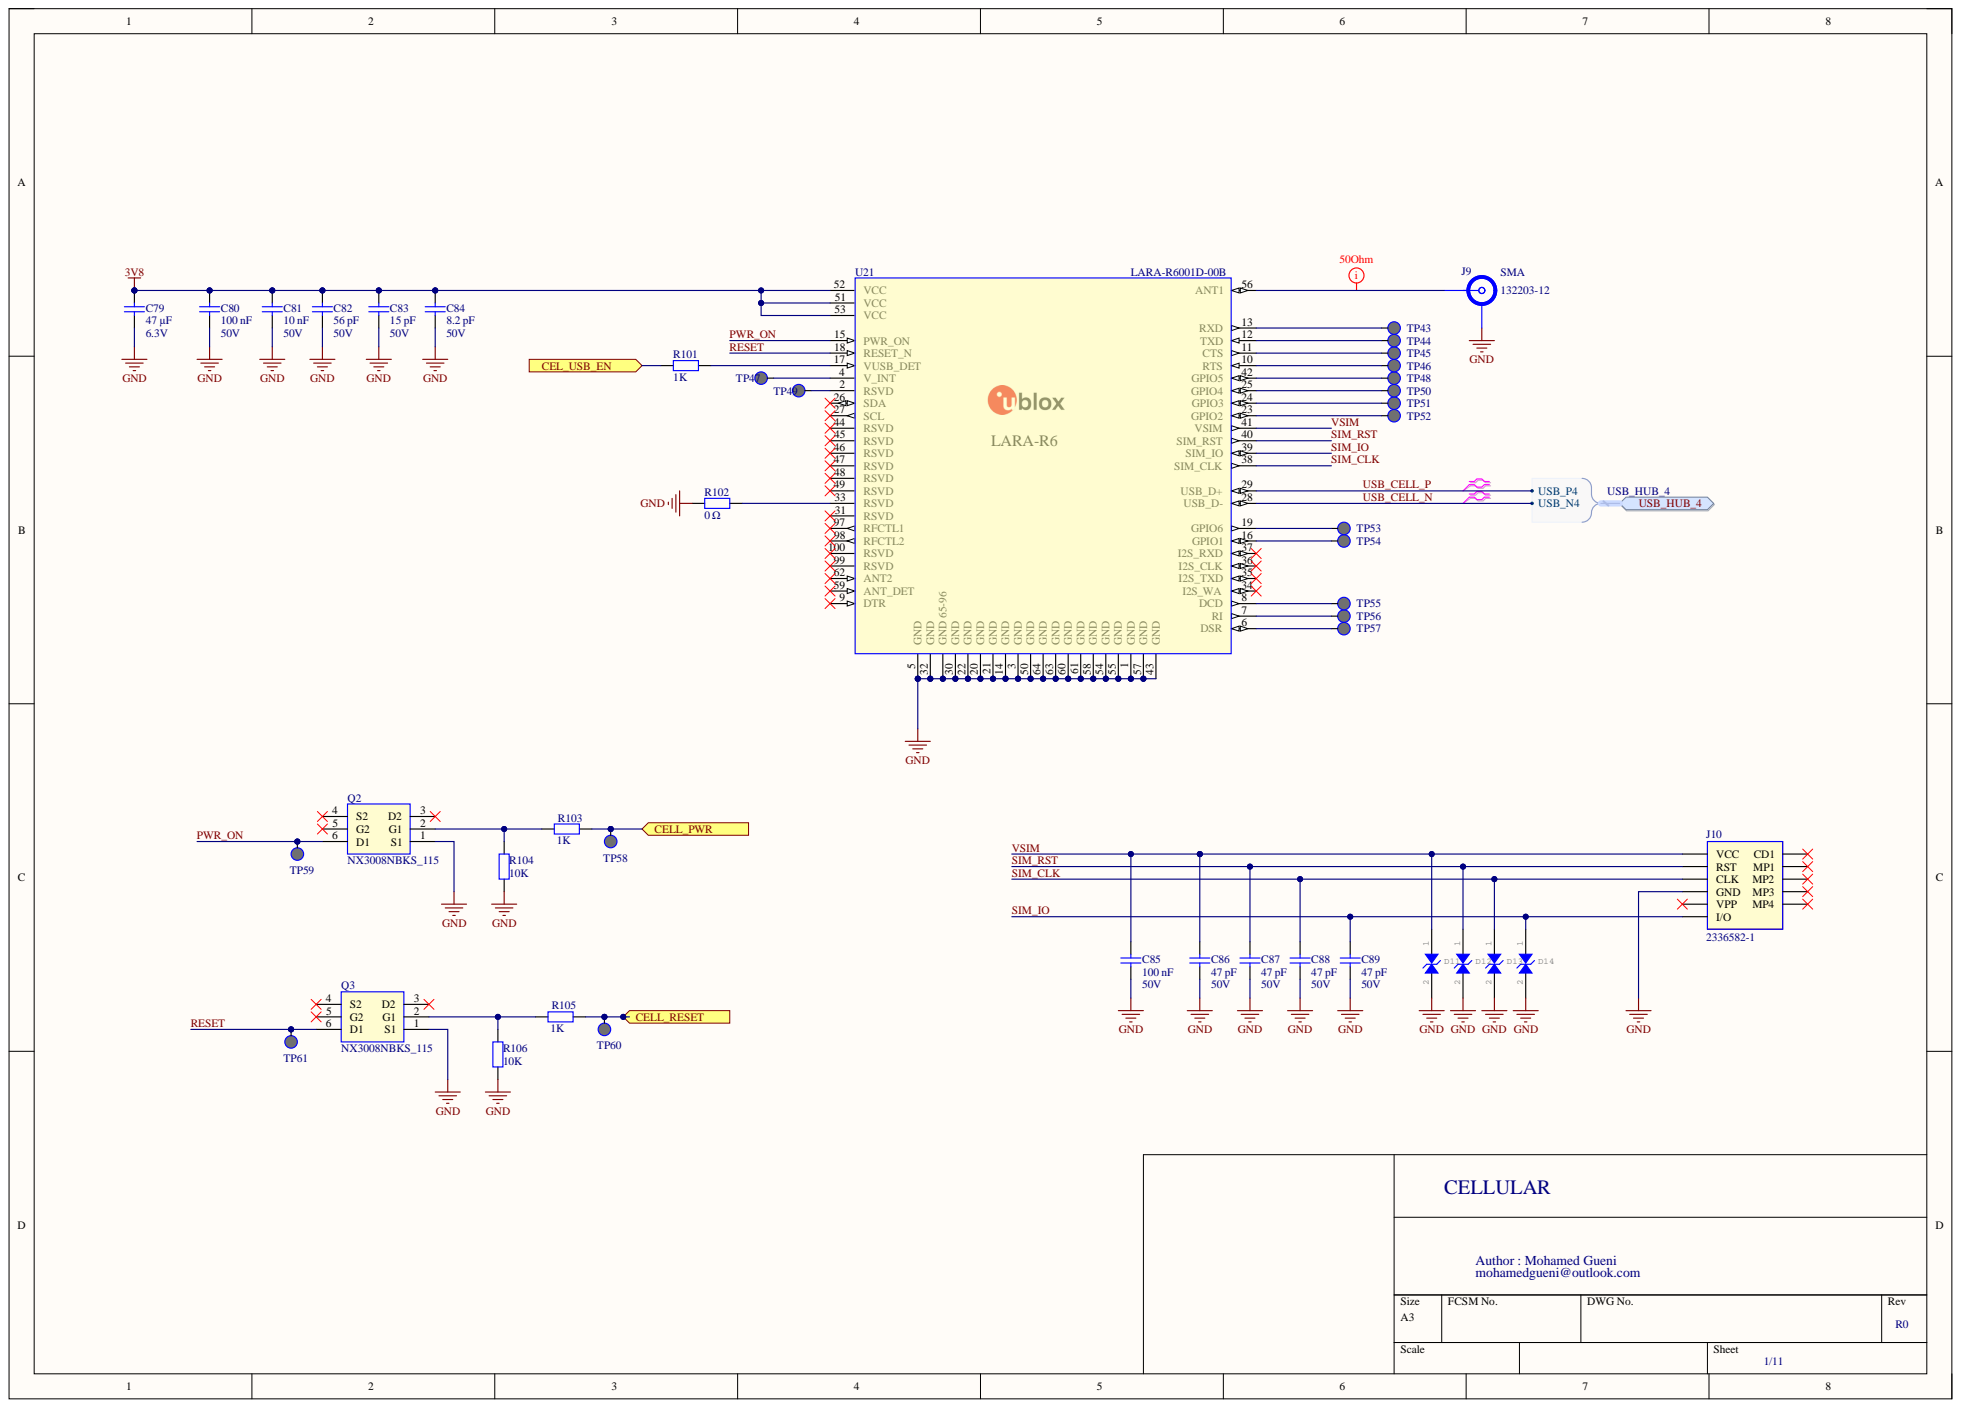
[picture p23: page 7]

GND GND

Author : Mohamed Gueni mohamedgueni@outlook.com

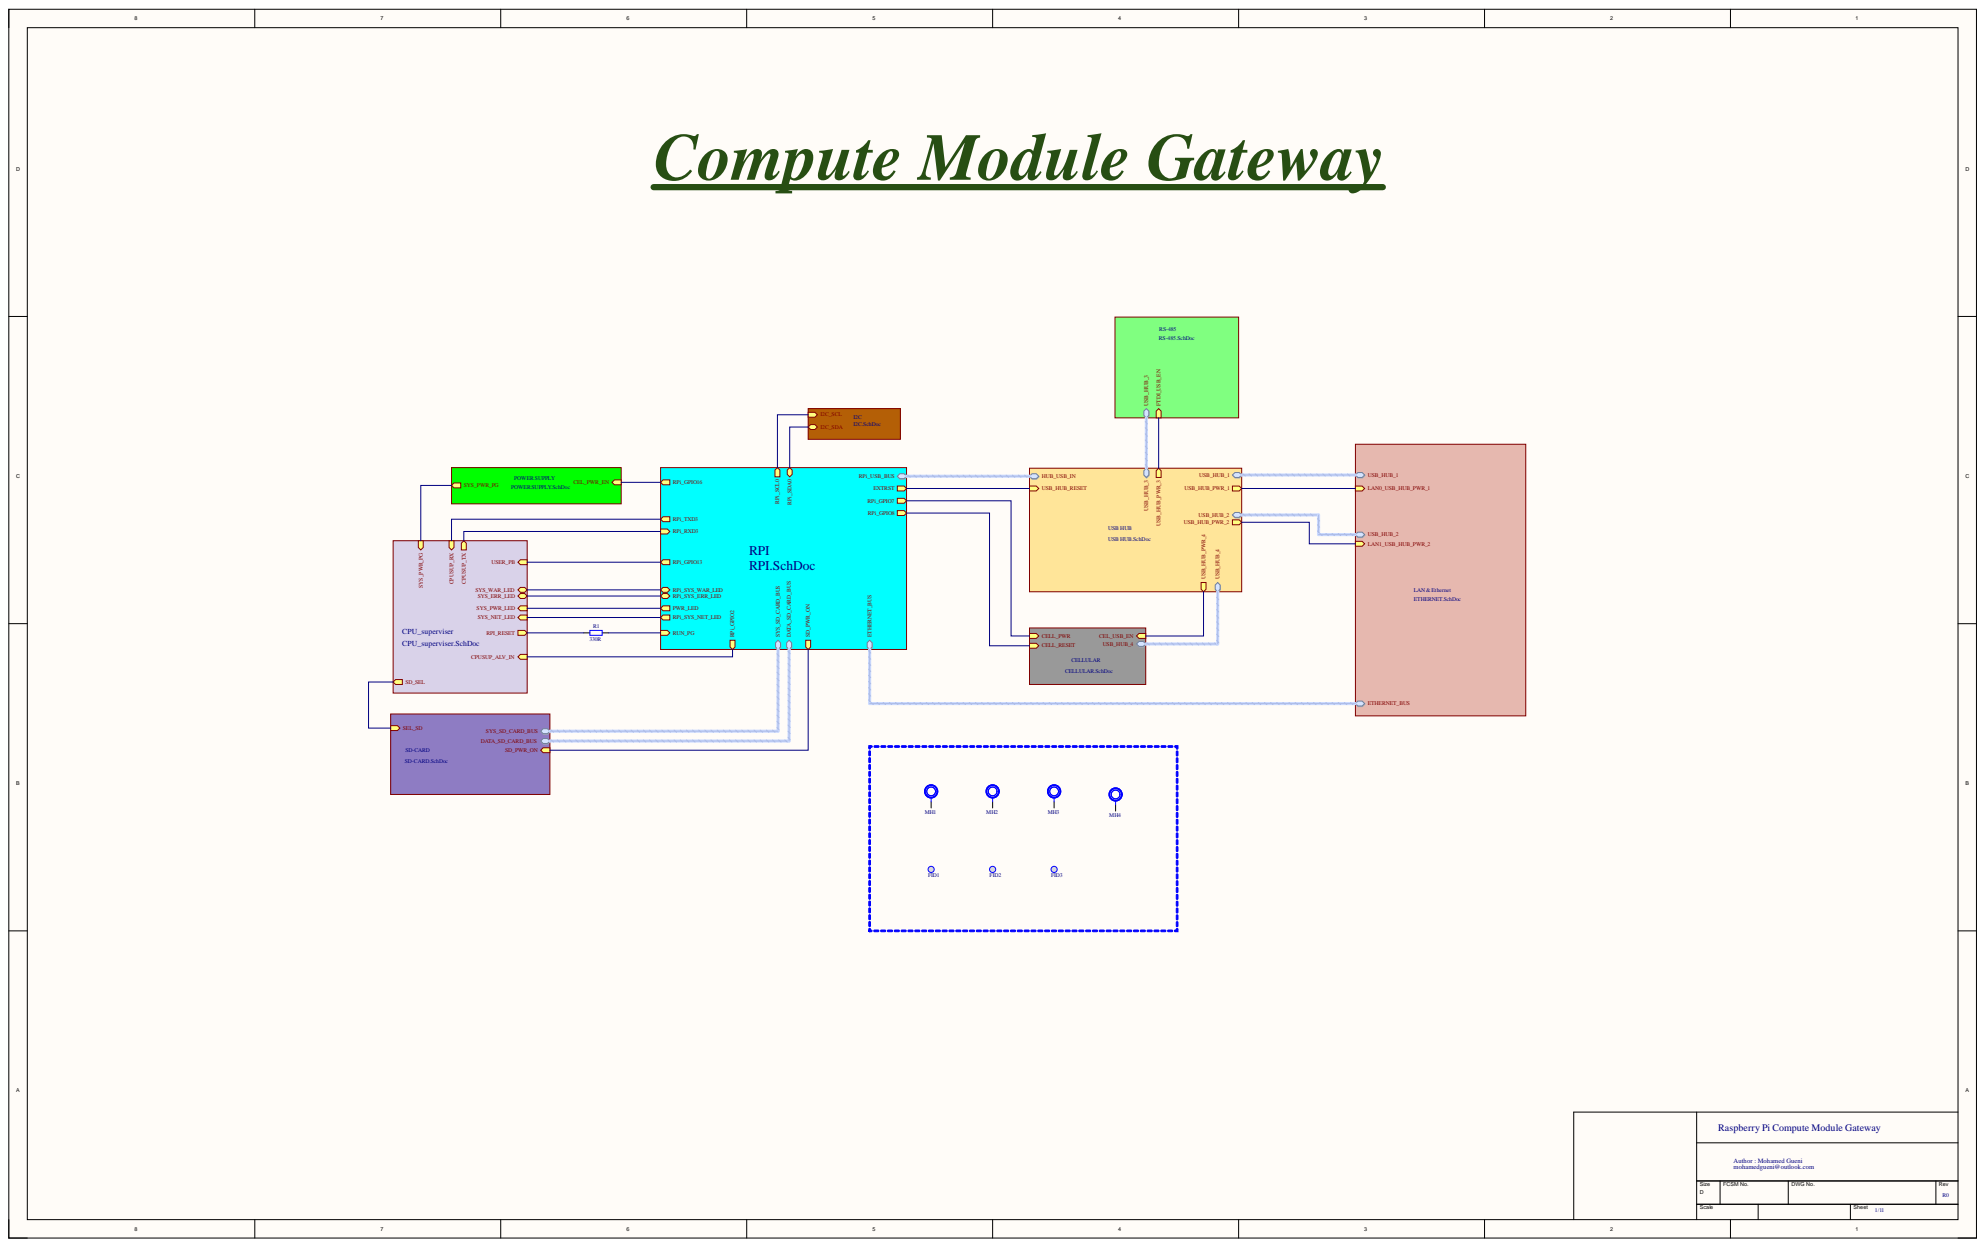
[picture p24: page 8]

Raspberry Pi Compute Module Gateway

Author : Mohamed Gueni mohamedgueni@outlook.com

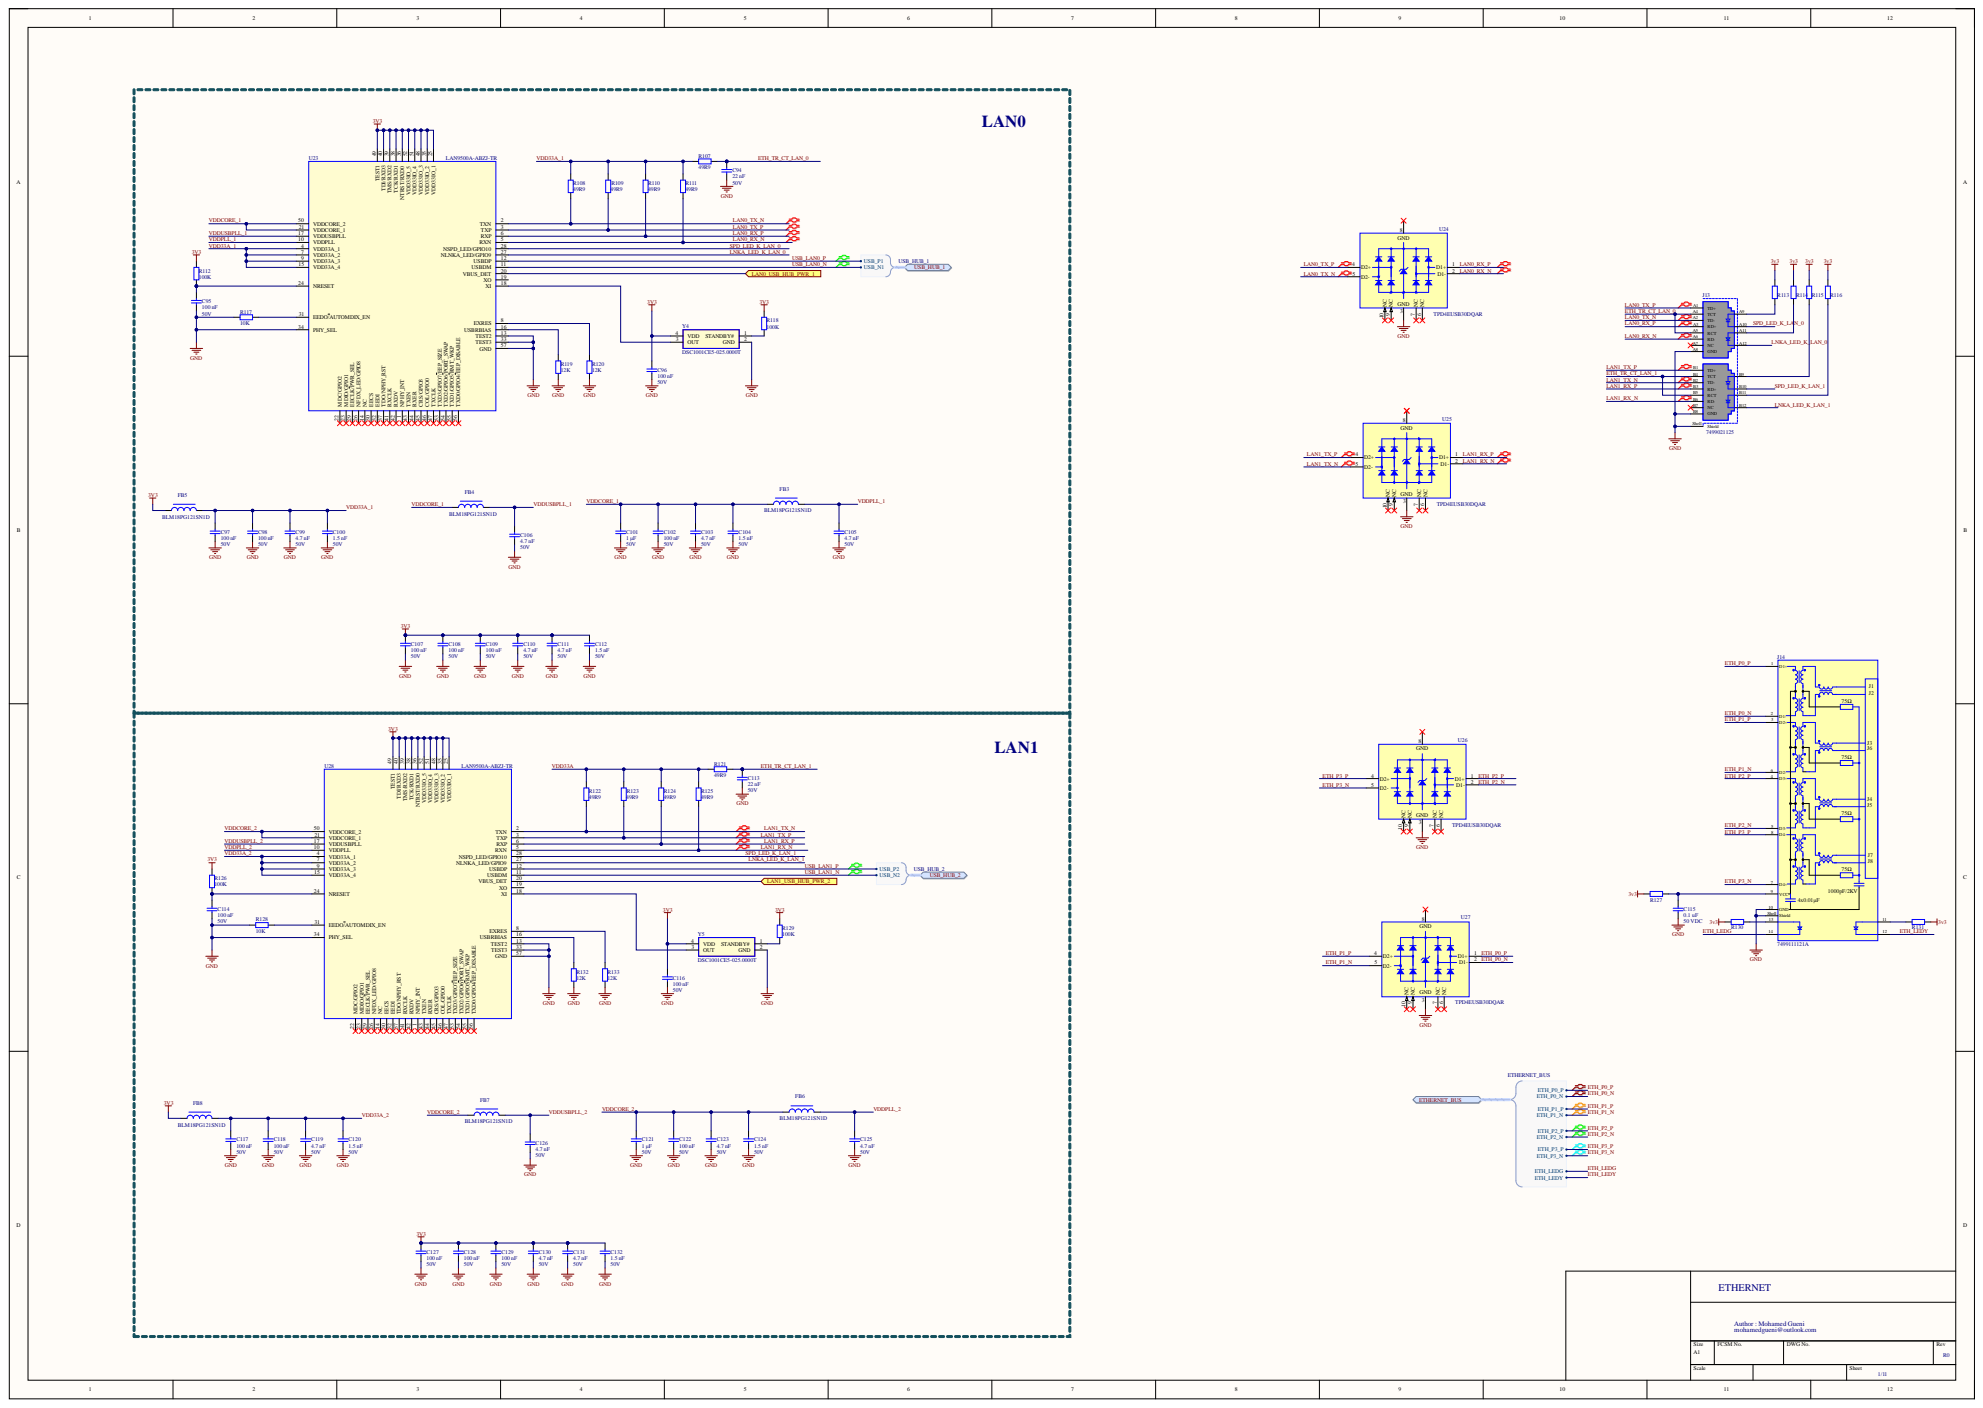
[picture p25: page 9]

TXCLK 47 COL/GPIO0 46 CRS/GPIO3 45 RXER 44 TXEN 43

Author : Mohamed Gueni mohamedgueni@outlook.com

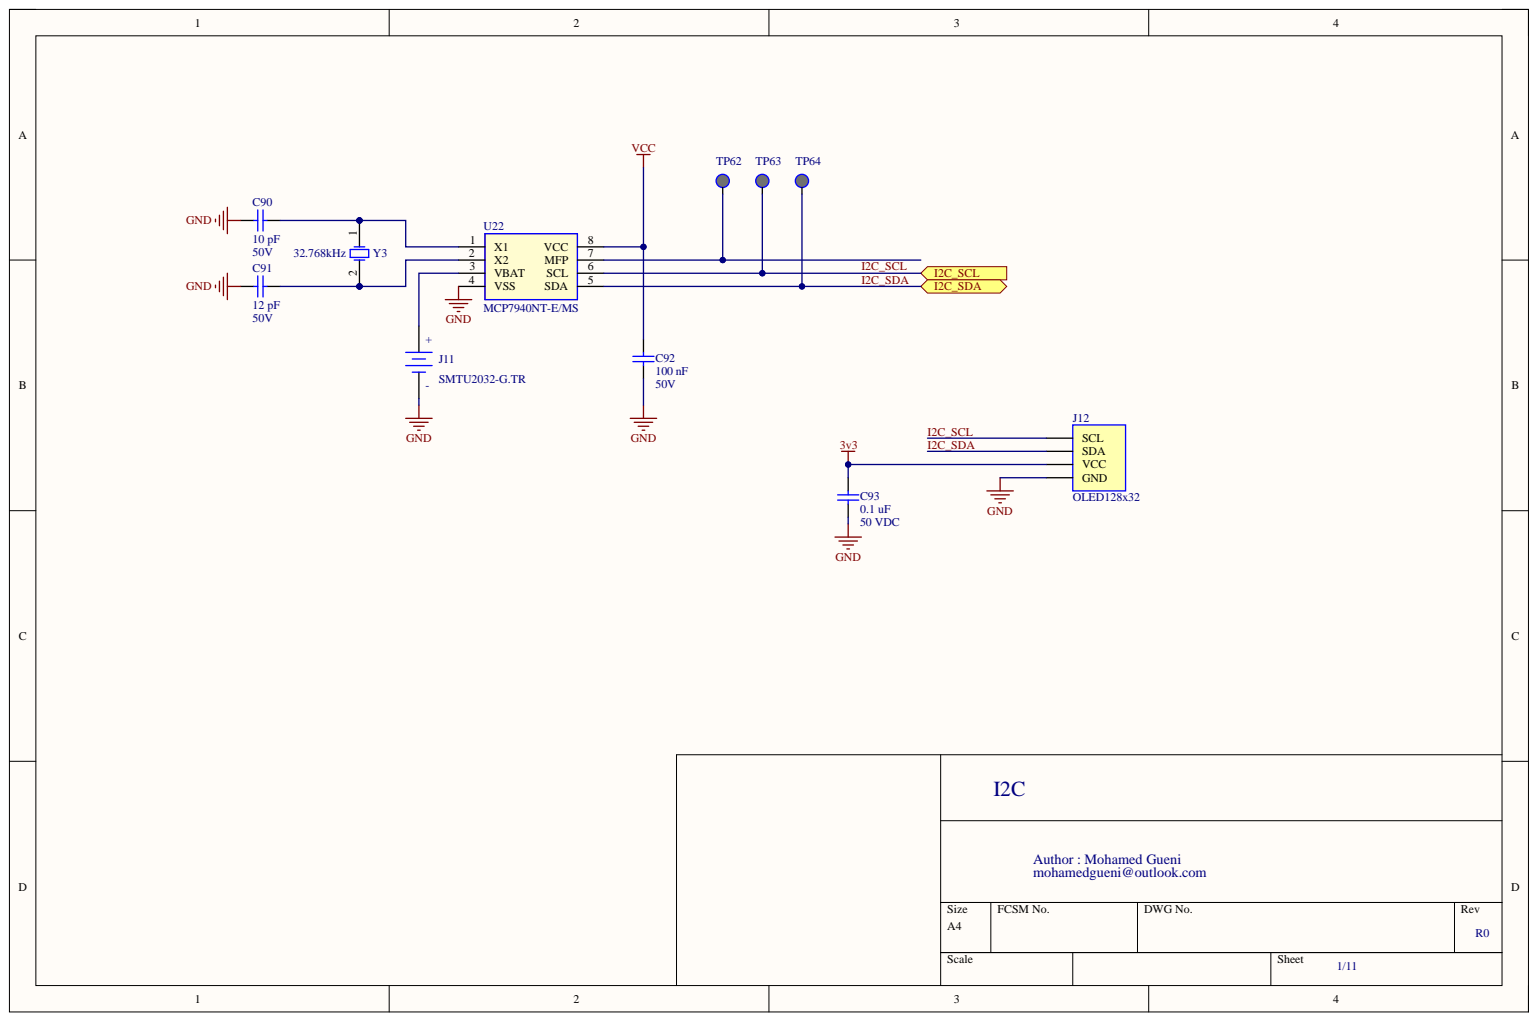
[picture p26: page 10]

3 | 6 | I2C_SCL

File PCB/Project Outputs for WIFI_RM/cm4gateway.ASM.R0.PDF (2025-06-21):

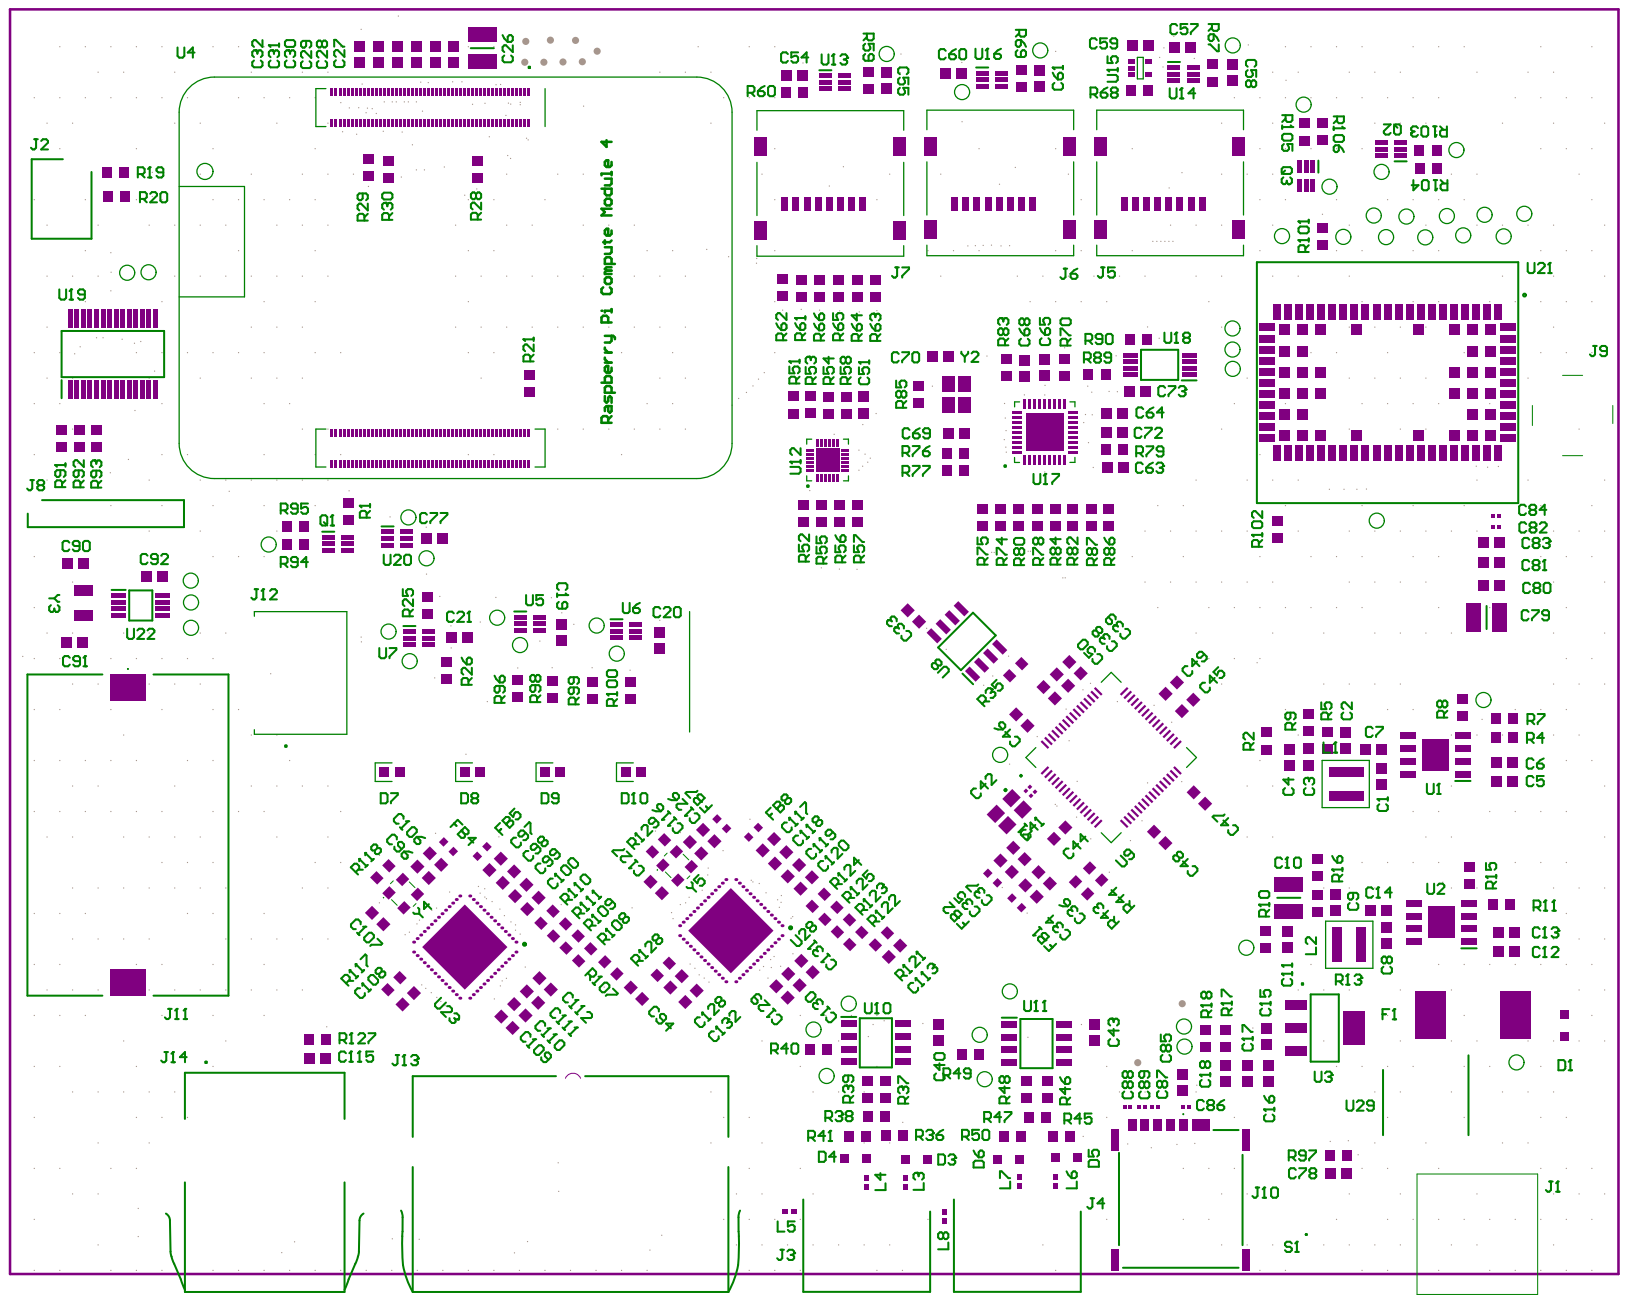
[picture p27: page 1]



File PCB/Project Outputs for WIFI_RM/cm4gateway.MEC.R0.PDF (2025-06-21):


View from Top side (Scale 1:1)






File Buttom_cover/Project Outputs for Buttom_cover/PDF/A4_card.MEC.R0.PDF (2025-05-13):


View from Top side (Scale 1:1)



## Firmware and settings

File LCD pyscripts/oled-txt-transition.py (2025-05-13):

import os
import math
import time
import subprocess                 
from time import sleep
from smbus import SMBus 
from lib_oled96 import ssd1306
from PIL import ImageFont, ImageDraw, Image

i2cbus = SMBus(1)
oled = ssd1306(i2cbus)
draw = oled.canvas   
padding = 2
shape_width = 20
top = padding
bottom = oled.height - padding - 1
x = padding
oled.display()
font = ImageFont.truetype('FreeMono.ttf', 14)

while True:
        ipaddress = os.popen("ifconfig wlan0 \
                            | grep 'inet addr' \
                            | awk -F: '{print $2}' \
                            | awk '{print $1}'").read()
        ssid = os.popen("iwconfig wlan0 \
                        | grep 'ESSID' \
                        | awk '{print $4}' \
                        | awk -F\\\" '{print $2}'").read()
        ipaddresseth = os.popen("ifconfig eth0 \
                            | grep 'inet addr' \
                            | awk -F: '{print $2}' \
                            | awk '{print $1}'").read()
        ssideth = os.popen("iwconfig eth0 \
                        | grep 'ESSID' \
                        | awk '{print $4}' \
                        | awk -F\\\" '{print $2}'").read()
        cmd = "hostname -I | cut -d\' \' -f1"
        IP = subprocess.check_output(cmd, shell = True )
        cmd = "top -bn1 | grep load | awk '{printf \"CPU Load: %.2f\", $(NF-2)}'"
        CPU = subprocess.check_output(cmd, shell = True )
        cmd = "free -m | awk 'NR==2{printf \"Mem: %s/%sMB %.2f%%\", $3,$2,$3*100/$2 }'"
        MemUsage = subprocess.check_output(cmd, shell = True )
        cmd = "df -h | awk '$NF==\"/\"{printf \"Disk: %d/%dGB %s\", $3,$2,$5}'"
        Disk = subprocess.check_output(cmd, shell = True )
        draw.rectangle((0, 0, oled.width-1, oled.height-1), outline=255, fill=1)
        oled.display()
        sleep(3)
        logo = Image.open('pi_logo.png')
        draw.bitmap((32, 0), logo, fill=0)
        oled.display()
        sleep(4)
        oled.cls()
        sleep(3)
        font = ImageFont.truetype('FreeMono.ttf', 14)
        draw.text((x+5, top+20), 'TIMEBOX 4.0', font=font, fill=1)
        oled.display()
        sleep(4)
        oled.cls()
        draw.text((x, top), "ssid: ", font=font, fill=1)
        draw.text((x, top+30), str(ssid), font=font, fill=1)
        oled.display()
        sleep(4)
        oled.cls()
        draw.text((x, top), "IP: ", font=font, fill=1)
        draw.text((x, top+30), str(IP), font=font, fill=1)
        oled.display()
        sleep(4)
        oled.cls()
        draw.text((x, top+30), str(CPU), font=font, fill=1)
        oled.display()
        sleep(4)
        oled.cls()
        draw.text((x, top+30), str(MemUsage), font=font, fill=1)
        oled.display()
        sleep(4)
        oled.cls()
        draw.text((x, top+30), str(Disk), font=font, fill=1)
        oled.display()
        sleep(4)
        oled.cls()
        draw.text((x, top), "ipaddresseth: ", font=font, fill=1)
        draw.text((x, top+30), str(ipaddresseth), font=font, fill=1)
        oled.display()
        sleep(4)
        oled.cls()
        draw.rectangle((0, 0, oled.width-1, oled.height-1), outline=255, fill=1)
        oled.display()
        sleep(3)

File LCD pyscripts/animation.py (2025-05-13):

import math
import time
import Adafruit_SSD1306
from PIL import Image
from PIL import ImageFont
from PIL import ImageDraw
from subprocess import check_output
import socket

def get_ip_address(ifname)
	s=socket.socket(socket.AF_INET, socket.SOCK_DGRAM)

RST                 = None 
disp                = Adafruit_SSD1306.SSD1306_128_32(rst=RST)
disp.begin()
width               = disp.width
height              = disp.height
disp.clear()
disp.display()
image               = Image.new('1', (width, height))
font                = ImageFont.load_default()
draw                = ImageDraw.Draw(image)
text                = str( check_output(['hostname', '-I']))
maxwidth, unused    = draw.textsize(text, font=font)
amplitude           = height/4
offset              = height/2 - 4
velocity            = -2
startpos            = width
print('Press Ctrl-C to quit.')
pos                 = startpos
while True:
    draw.rectangle((0,0,width,height), outline=0, fill=0)
    x               = pos
    for i, c in enumerate(text):
        if x > width:
            break
        if x < -10:
            char_width, char_height = draw.textsize(c, font=font)
            x += char_width
            continue
        y = offset+math.floor(amplitude)
        draw.text((x, y), c, font=font, fill=255)
        char_width, char_height = draw.textsize(c, font=font)
        x += char_width
    disp.image(image)
    disp.display()
    pos += velocity
    if pos < -maxwidth:
        pos = startpos
    time.sleep(0.1)

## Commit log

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2025-05-14 Add new PCB schematic files for CPU supervisor, LAN0, LAN1, and USB HUB; remove HMI schematic
    [CPU_superviser.SchDoc, HMI.SchDoc, LAN0.SchDoc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]
2025-05-14 Add new schematic documents for CPU supervisor, LAN0, LAN1, and USB HUB; remove HMI schematic
    [I2C.SchDoc, RPI.SchDoc, cm4gateway.PrjPcb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]
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2025-05-20 Update PCB project files and add new harness
    - Modified the cm4gateway.PrjPcb file to update the AnnotateOrder values for multiple documents, ensuring proper annotation sequencing.
    - Updated the cm4gateway.SchDoc file, which has binary differences indicating changes in the schematic document.
    - Created a new cm4gateway.Harness file to define Ethernet connections, enhancing the project's hardware interface specifications.
    [cm4gateway.PrjPcb, cm4gateway.SchDoc]
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2025-05-26 Update database and schematic library files; add log for part replacement in power supply schematic
    [POWER SUPPLY.SchDoc]
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2025-06-05 Update component designators and modify binary files
    - Changed multiple component designators in the power supply schematic log, updating old designators to new ones for clarity and organization.
    - Updated binary files: DB.mdb and SCH.SchLib, reflecting necessary changes in the project.
    [POWER SUPPLY.SchDoc]
2025-06-06 Remove obsolete Ethernet and LAN schematic files; add new Rpi schematic file
    [CELLULAR.SchDoc, ETHERNET.SchDoc, LAN0.SchDoc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]
2025-06-07 Add Ethernet harness and update project files
    - Introduced a new document section for ETHERNET.Harness in cm4gateway.PrjPcb with annotation settings and library updates.
    - Updated SCH.SchLib with binary changes.
    - Created a new ETHERNET.Harness file defining USB connections.
    [CELLULAR.SchDoc, ETHERNET.SchDoc, cm4gateway.PrjPcb]
2025-06-07 Update PCB project files and logs for component designator changes
    - Added new document section for CELLULAR.Harness in cm4gateway.PrjPcb.
    - Updated PartTypes setting in cm4gateway.PrjPcb from 0 to 1.
    - Modified binary files: DB.mdb and SCH.SchLib.
    - Created new CELLULAR.Harness file with USB pin definitions.
    - Added multiple project log files documenting changes to component designators across various sections (CELLULAR, ETHERNET, POWER SUPPLY, RS-485) with detailed old and new designator mappings.
    - Updated DB.ldb with new entries.
    [CELLULAR.SchDoc, ETHERNET.SchDoc, POWER SUPPLY.SchDoc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]
2025-06-07 Update component designators and add RS-485 harness configuration
    - Changed various component designators in the schematic logs:
    - Updated capacitors (C?) to C1, C2
    - Updated diodes (D?) to D1, D2, D3, D4
    - Updated jumpers (J?) to J1, J14, J13
    - Updated resistors (R?) to R2, R3, R4, R5, R6, R117, R118, R119, R120, R121, R122, R123
    - Updated ICs (U?) to U29, U30, U31, U32
    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
    [CELLULAR.SchDoc, CPU_superviser.SchDoc, ETHERNET.SchDoc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]
2025-06-08 Refactor PCB project files: removed obsolete harness, updated parameters, and modified component designators
    - Deleted the cm4gateway.Harness file as it was no longer needed.
    - Updated cm4gateway.PrjPcb to reflect new parameter names and values, ensuring consistency across the project.
    - Removed redundant LAN1 entry from cm4gateway.PrjPcbStructure.
    - Updated component designators in the project log for clarity and organization.
    [CPU_superviser.SchDoc, ETHERNET.SchDoc, I2C.SchDoc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]
2025-06-09 Refactor component designators across multiple schematics for cm4gateway project
    - Updated designators for capacitors, jumpers, test points, and resistors in various schematic files.
    - Adjusted designators in the following logs:
    - CELLULAR SCH ECO
    - CPU_superviser SCH ECO
    - ETHERNET SCH ECO
    - I2C SCH ECO
    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
    [CELLULAR.SchDoc, CPU_superviser.SchDoc, ETHERNET.SchDoc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]
2025-06-09 Update PCB project files for cm4gateway
    - Disabled ClassGenCCAutoRoomEnabled in multiple sections to streamline class generation settings.
    - Revised parameters in the PCB project file, including updating the revision and PCB assembly number.
    - Removed redundant parameters and consolidated relevant information for clarity.
    - Updated the schematic document, indicating a binary change without specific details.
    [ETHERNET.SchDoc, RS-485.SchDoc, Rpi.SchDoc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]
2025-06-09 Refactor PCB design for cm4gateway
    - Removed several components from various classes including RS-485, SD-CARD, USB HUB, and CPU_superviser.
    - Added new components and members to classes such as POWER SUPPLY, RPI, and RS-485, including capacitors, resistors, and ICs.
    - Introduced a new OLED128x32 component with associated parameters and net connections.
    - Updated component designators for MH1 and MH2, ensuring proper identification in the schematic.
    - Replaced multiple parts in the schematic with components from the database library, enhancing consistency and reliability.
    - Addressed unknown pin connections for several components, ensuring all pins are accounted for in the design.
    [CELLULAR.SchDoc, CPU_superviser.SchDoc, ETHERNET.SchDoc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]
2025-06-09 Update PCB structure and remove obsolete database files
    - Modified the PCB structure to change the designator for the LAN0 sheet symbol to "LAN & Ethernet" for better clarity.
    - Deleted the obsolete DB.ldb file from the lib directory.
    - Updated the DB.mdb file, reflecting changes in the database structure or content.
    [CPU_superviser.SchDoc]
2025-06-09 Update PCB design files for cm4gateway with component replacements and net additions
    - Replaced multiple capacitors (C62-C73) and resistors (R70-R90) in USB HUB schematic with components from the database library.
    - Updated USB HUB schematic with new TP and USB2514 components.
    - Added unknown pins to nets for components U5, U6, U7, and U20 in multiple PCB ECO logs.
    - Added new components U5, U6, U7, and U20 with detailed parameters including manufacturer, part number, and datasheet links.
    - Replaced fiducials and MH components in cm4gateway schematic with updated library components.
    - Added new database entry for GF6312UCX component.
    [CAO_TimeSys.step.DWG, CELLULAR.SchDoc, CPU_superviser.SchDoc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]
2025-06-09 Update PCB design for cm4gateway: replaced multiple capacitors and resistors with components from the database library, added new components U5, U6, U7, and U20 with detailed parameters, and updated 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
2025-06-10 Refactor code structure and remove redundant sections for improved readability and maintainability
    [CELLULAR.SchDoc, CPU_superviser.SchDoc, ETHERNET.SchDoc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]
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2025-06-10 Update cm4gateway PCB design and project logs
    - Modified net connections by removing pins from the 3v8 net and adding them to the 5V net for components R10, R12, and R14.
    - Added a new rule for schematic supply nets named "Schematic Supply Nets_12".
    - Created a new project log detailing the changes made during the ECO process on June 10, 2025.
    [POWER SUPPLY.SchDoc]
2025-06-10 Update PCB and database files; add ECO log for cm4gateway changes
    - Updated PCB schematic file (cm4gateway.SchDoc) with new design changes.
    - Modified database file (DB.ldb) to reflect recent updates.
    - Added project log for cm4gateway detailing the removal of member FID4 from ClassName=cm4gateway.
    [cm4gateway.SchDoc]
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2025-06-10 Update PCB components and footprints across multiple schematics
    - Replaced various capacitors, resistors, inductors, and TVS diodes in RS-485, SD-CARD, and USB HUB schematics with components from the database library.
    - Updated component parameters, including designators, footprints, and comments for improved clarity and accuracy.
    - Removed and added pins from specific nets in the cm4gateway PCB, ensuring proper connectivity.
    - Changed physical footprints for several components to match updated specifications.
    - Documented changes in project logs for traceability and future reference.
    [CELLULAR.SchDoc, CPU_superviser.SchDoc, ETHERNET.SchDoc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]
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
